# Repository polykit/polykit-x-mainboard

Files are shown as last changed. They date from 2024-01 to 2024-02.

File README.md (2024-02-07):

# Polykit X8 Mainboard

_THIS IS NOT A FINISHED PRODUCT IN ANY WAY AND STILL UNDER HEAVY DEVELOPMENT - USE AT YOUR OWN RISK!_

This repository contains Kicad schematics and PCB layout for a main board for a polyphonic synthesizer that is controlled by a micro controller.

Key features:

* 8 voice cards
* 16-bit DAC
* Atmel2560 micro controller
* Eurorack powered
* MIDI input/output

All parameters of the voice cards are controlled by the DAC. That means patches can be stored and recalled.

There is a video playlist on the design process https://makertube.net/w/p/3N2fRjXwT2SfAUv2VkMy3e

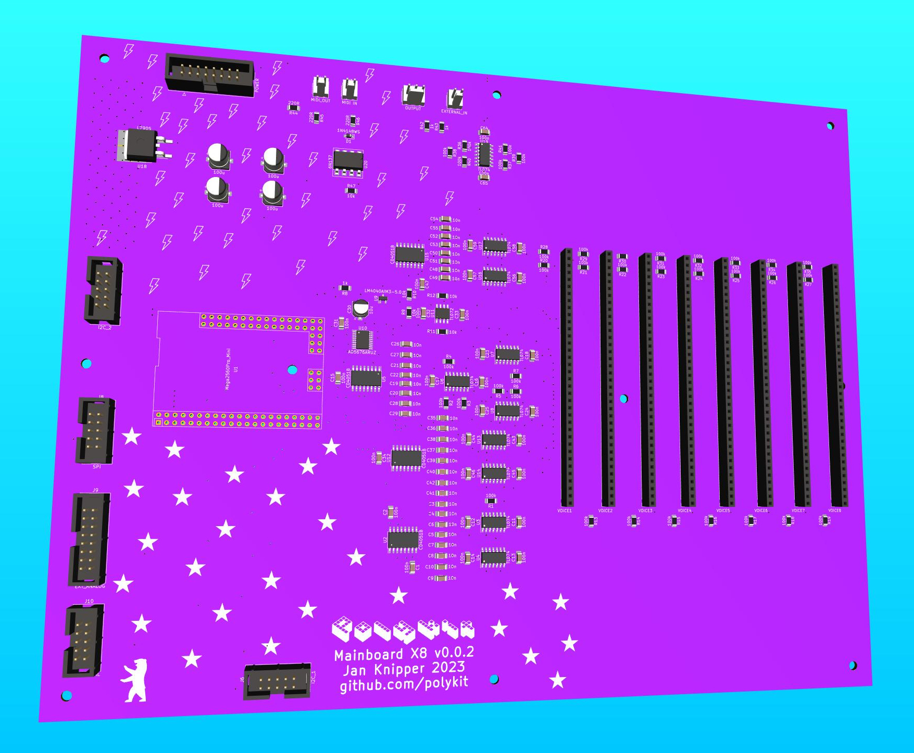
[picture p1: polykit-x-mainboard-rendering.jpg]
Polykit X8 Main Board Rendering


Related repositories:

* Voice Card: https://github.com/polykit/polykit-x-voice-card
* Control Board: https://github.com/polykit/polykit-x-controlboard
* Input Board: _soon_
* Software: _soon_
* Power Supply: https://github.com/polykit/eurorack-psu

## BOM

|Reference |Value |Footprint |Qty|
|---|---|---|---|
|C1, C2, C11-C18, C23-C25, C31-C34, C43-C47, C56-C59, C64, C65|100n ceramic |Capacitor_SMD:C_1206_3216Metric_Pad1.33x1.80mm_HandSolder |28 |
|C3-C10, C19-C22, C26-C29, C35-C42, C48-C55 |10n film, PPS |Capacitor_SMD:C_1206_3216Metric_Pad1.33x1.80mm_HandSolder |32 |
|C30 |10u |Capacitor_SMD:CP_Elec_5x5.9 |1  |
|C60-C63 |100u |Capacitor_SMD:CP_Elec_6.3x7.7 |4  |
|D1 |1N4148WS |Diode_SMD:D_SOD-323_HandSoldering |1  |
|J1 |POWER |Connector_IDC:IDC-Header_2x08_P2.54mm_Vertical |1  |
|J2 |OUTPUT |Connector_Molex:Molex_KK-254_AE-6410-03A_1x03_P2.54mm_Vertical|1  |
|J3 |MIDI IN |Connector_Molex:Molex_KK-254_AE-6410-02A_1x02_P2.54mm_Vertical|1  |
|J4 |MIDI_OUT |Connector_Molex:Molex_KK-254_AE-6410-02A_1x02_P2.54mm_Vertical|1  |
|J5 |EXTERNAL_IN |Connector_Molex:Molex_KK-254_AE-6410-02A_1x02_P2.54mm_Vertical|1  |
|J6 |I2C_1 |Connector_IDC:IDC-Header_2x05_P2.54mm_Vertical |1  |
|J7 |I2C_2 |Connector_IDC:IDC-Header_2x05_P2.54mm_Vertical |1  |
|J8 |SPI |Connector_IDC:IDC-Header_2x05_P2.54mm_Vertical |1  |
|J9 |EXT_ANALOG |Connector_IDC:IDC-Header_2x08_P2.54mm_Vertical |1  |
|J10 |EXT_DIGITAL |Connector_IDC:IDC-Header_2x05_P2.54mm_Vertical |1  |
|R1-R7, R13-R41 |100k |Resistor_SMD:R_1206_3216Metric_Pad1.30x1.75mm_HandSolder |36 |
|R8, R42, R43 |1k |Resistor_SMD:R_1206_3216Metric_Pad1.30x1.75mm_HandSolder |3  |
|R9-R12, R47 |10k |Resistor_SMD:R_1206_3216Metric_Pad1.30x1.75mm_HandSolder |5  |
|R44-R46 |220R |Resistor_SMD:R_1206_3216Metric_Pad1.30x1.75mm_HandSolder |3  |
|U1 |Mega2560Pro_Mini|aga:Mega2560Pro_Embed_RobotDyn |1  |
|U2, U5, U12, U15 |CD4051B |Package_SO:SO-16_5.3x10.2mm_P1.27mm |4  |
|U3, U4, U6-U8, U13, U14, U16, U17, U19 |TL074 |Package_SO:SO-14_3.9x8.65mm_P1.27mm |10 |
|U9 |LM4040AIM3-5.0  |Package_TO_SOT_SMD:SOT-23 |1  |
|U10 |AD5676ARUZ |Package_SO:TSSOP-20_4.4x6.5mm_P0.65mm |1  |
|U11 |TL072 |Package_SO:SO-8_3.9x4.9mm_P1.27mm |1  |
|U18 |L7905 |Package_TO_SOT_SMD:TO-263-2 |1  |
|U20 |6N137 |Package_DIP:DIP-8_W7.62mm_SMDSocket_SmallPads |1  |
|VOICE1-VOICE8 |VOICE |Connector_PinSocket_2.54mm:PinSocket_1x36_P2.54mm_Vertical |8  |

## Tweaks

* If saw/triangle signal is not audible replace R38 with a 220k resistor on the voice cards

## References

https://www.analog.com/media/en/technical-documentation/data-sheets/ad5676.pdf

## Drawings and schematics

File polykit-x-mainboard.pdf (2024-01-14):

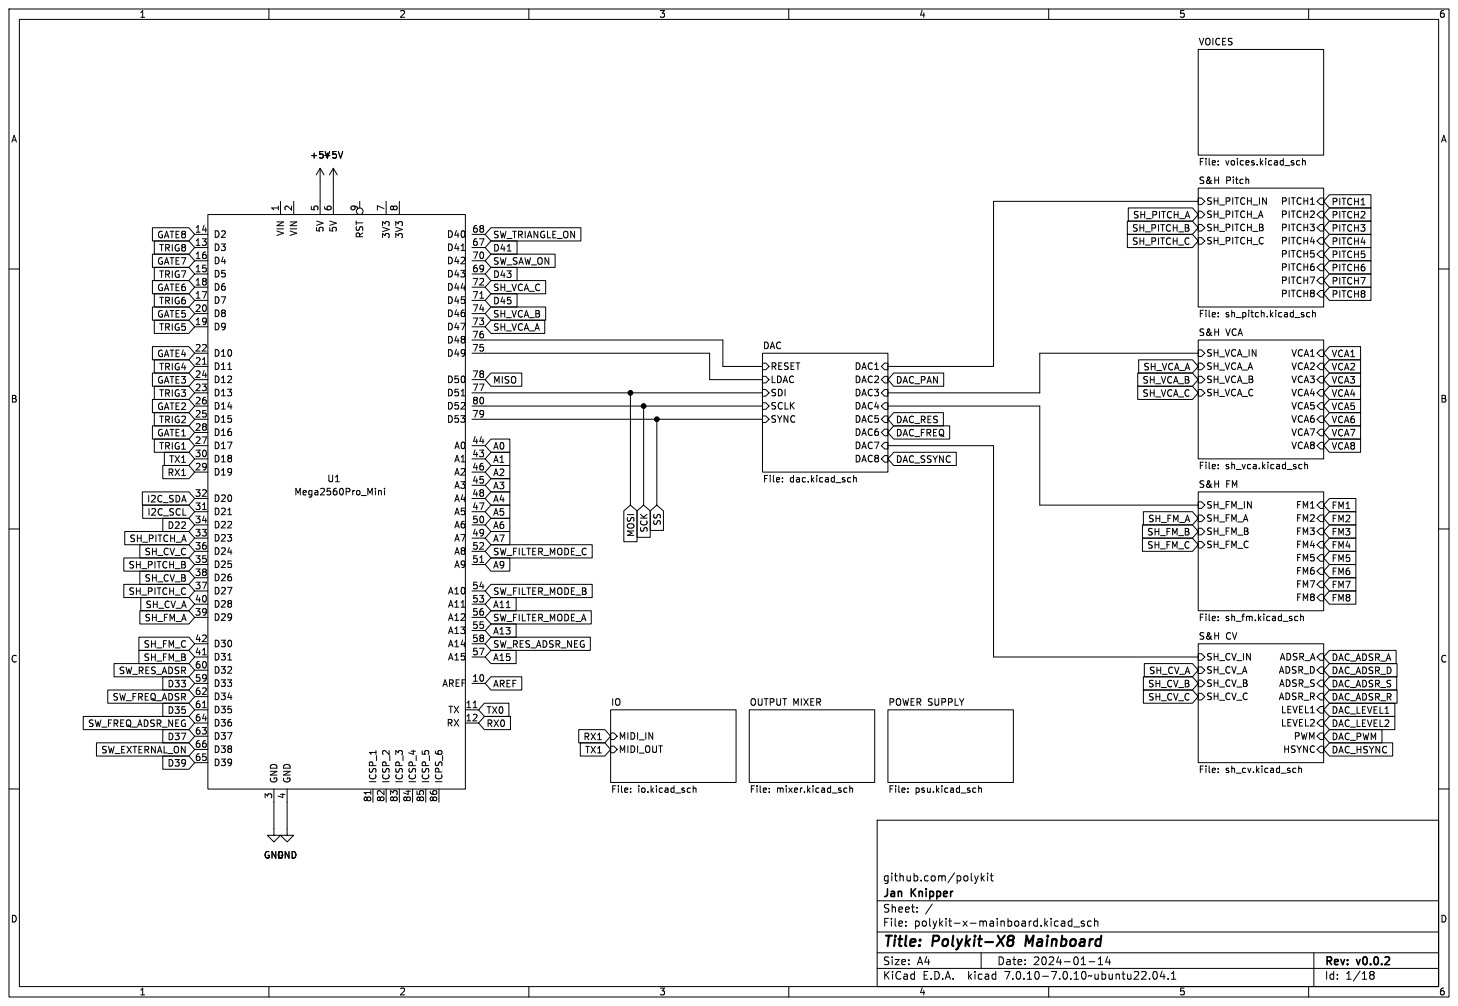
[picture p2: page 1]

SH_VCA_B
File: dac.kicad_sch OUTPUT MIXER

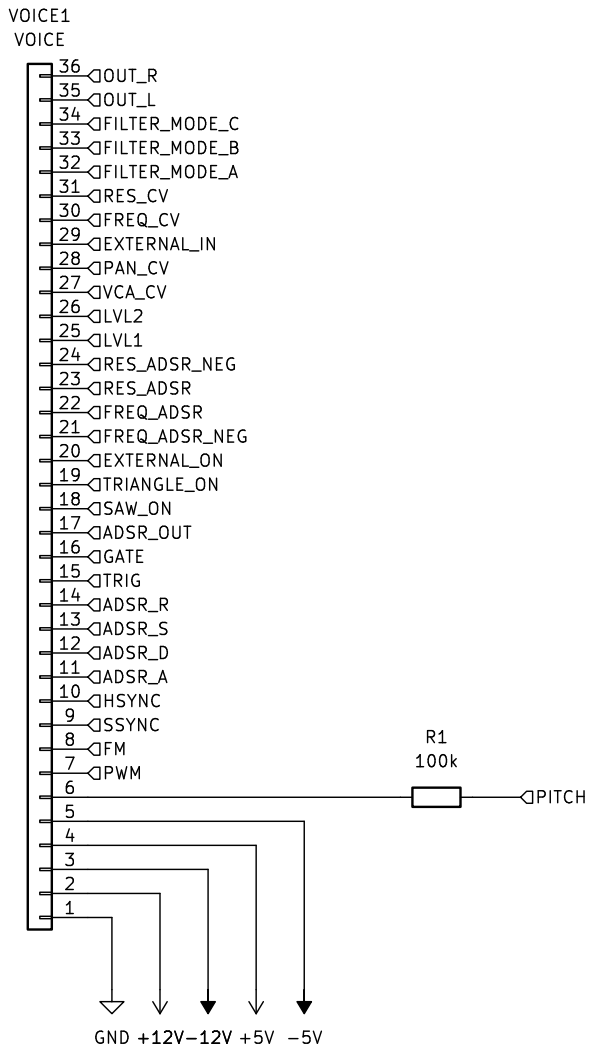
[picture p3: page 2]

github.com/polykit GND +12V -12V +5V -5V 1

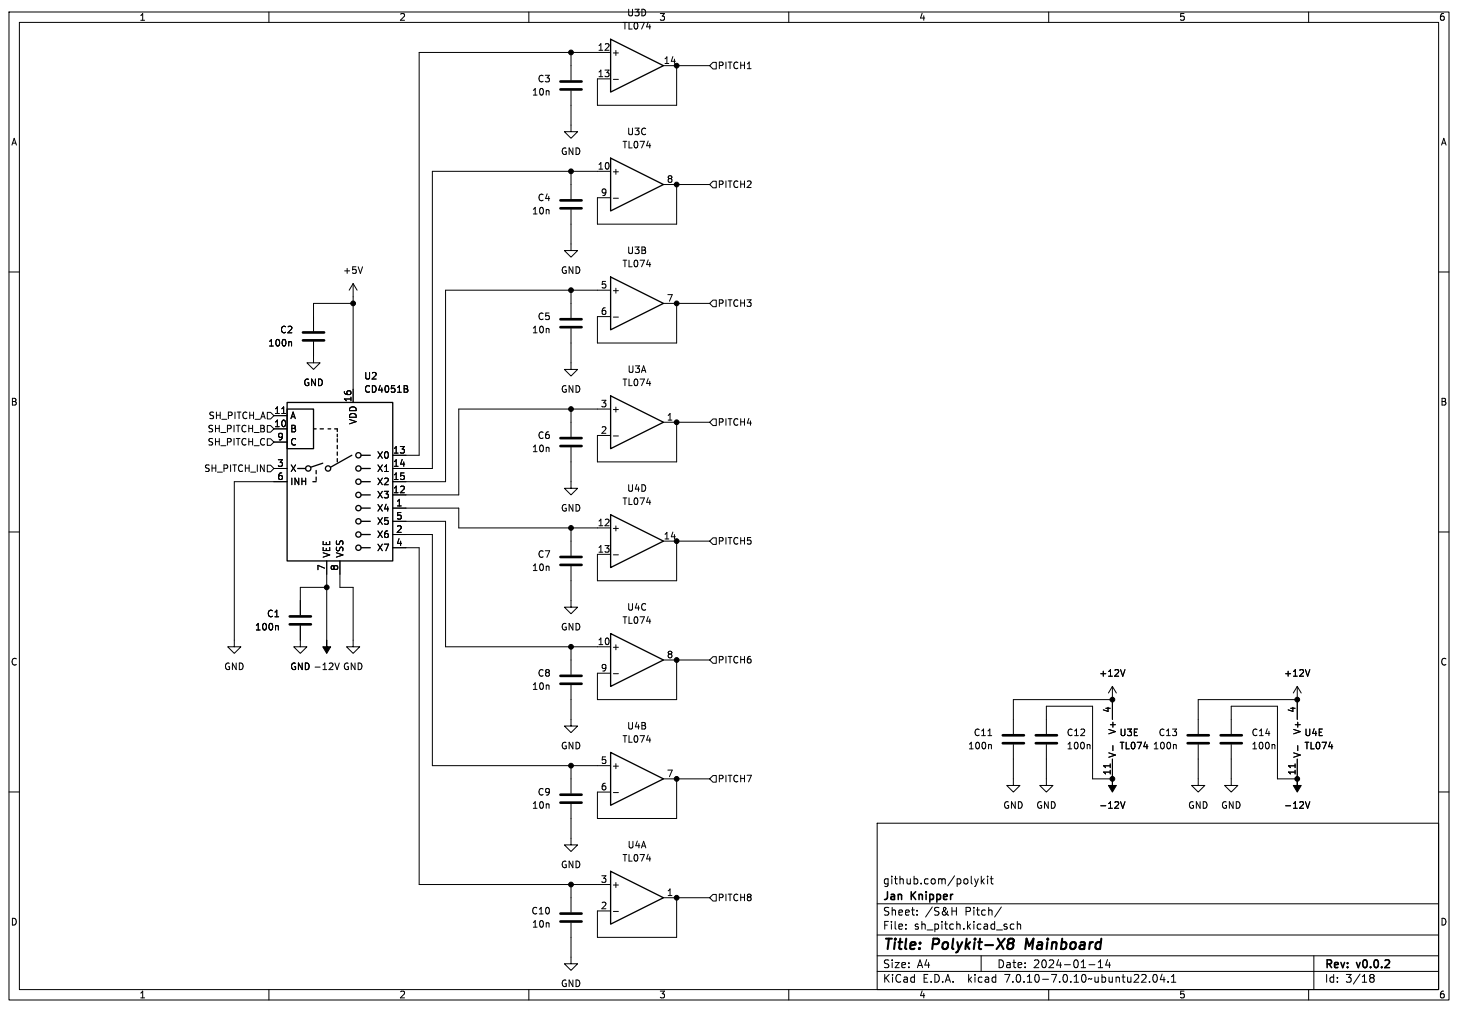
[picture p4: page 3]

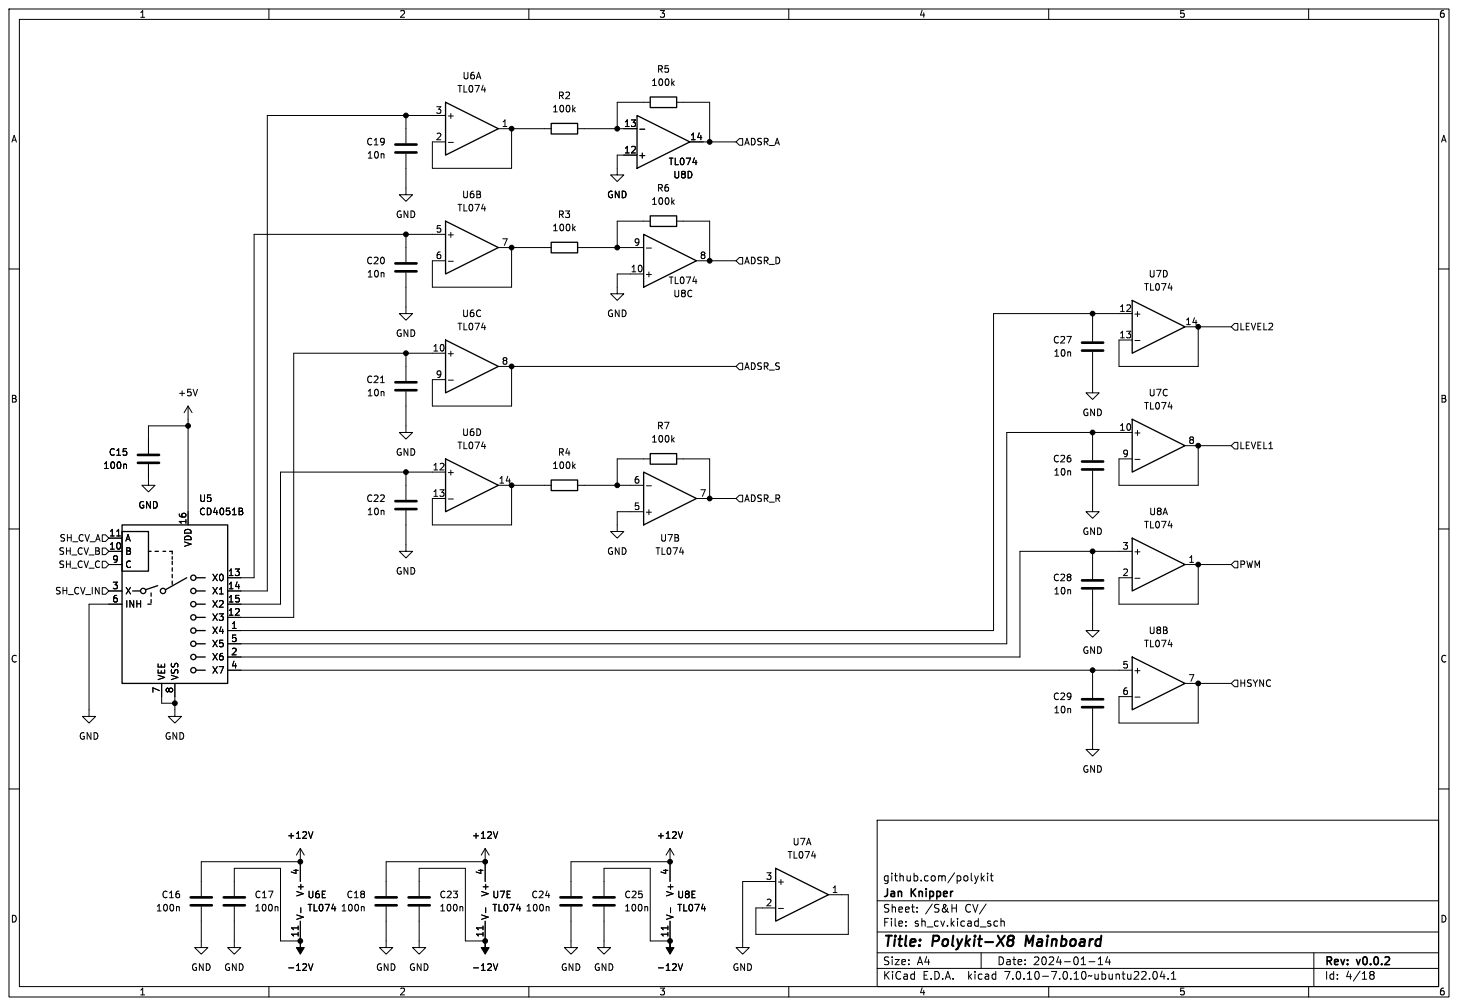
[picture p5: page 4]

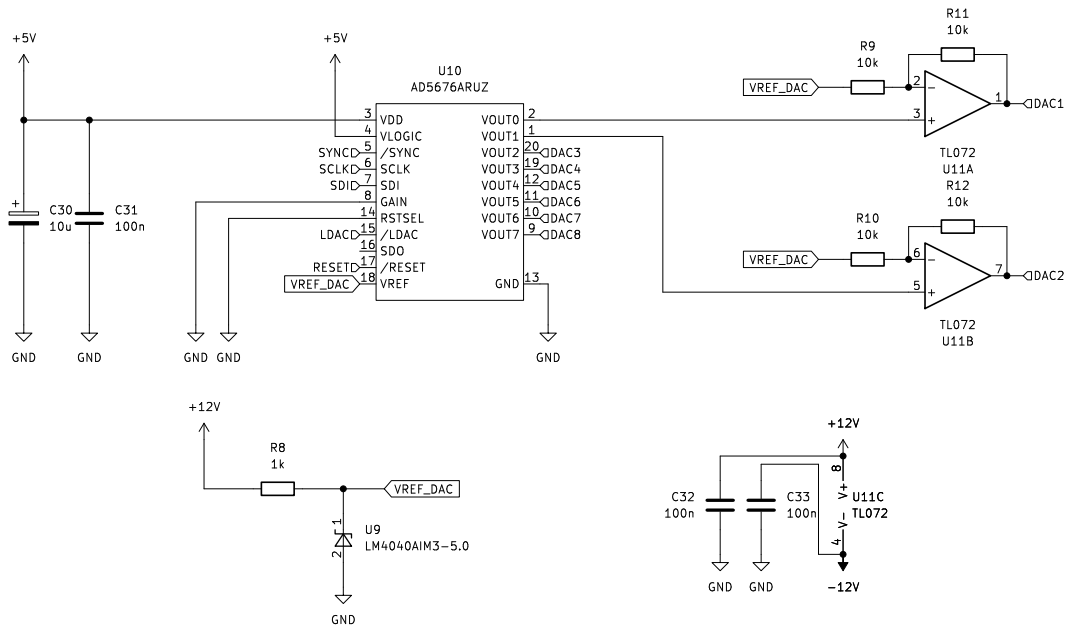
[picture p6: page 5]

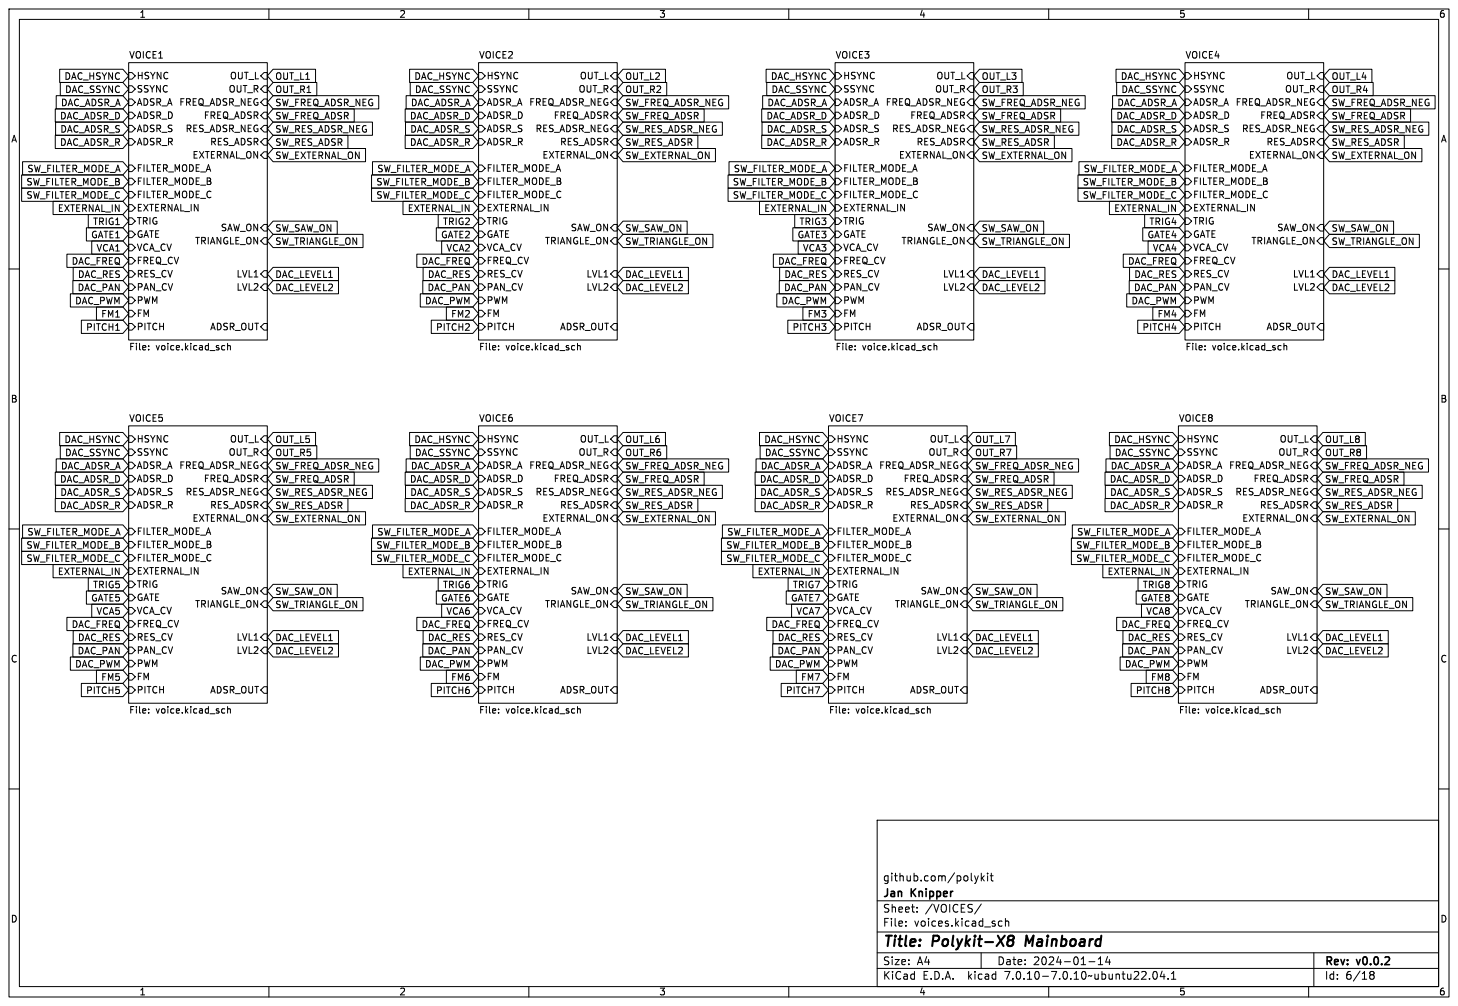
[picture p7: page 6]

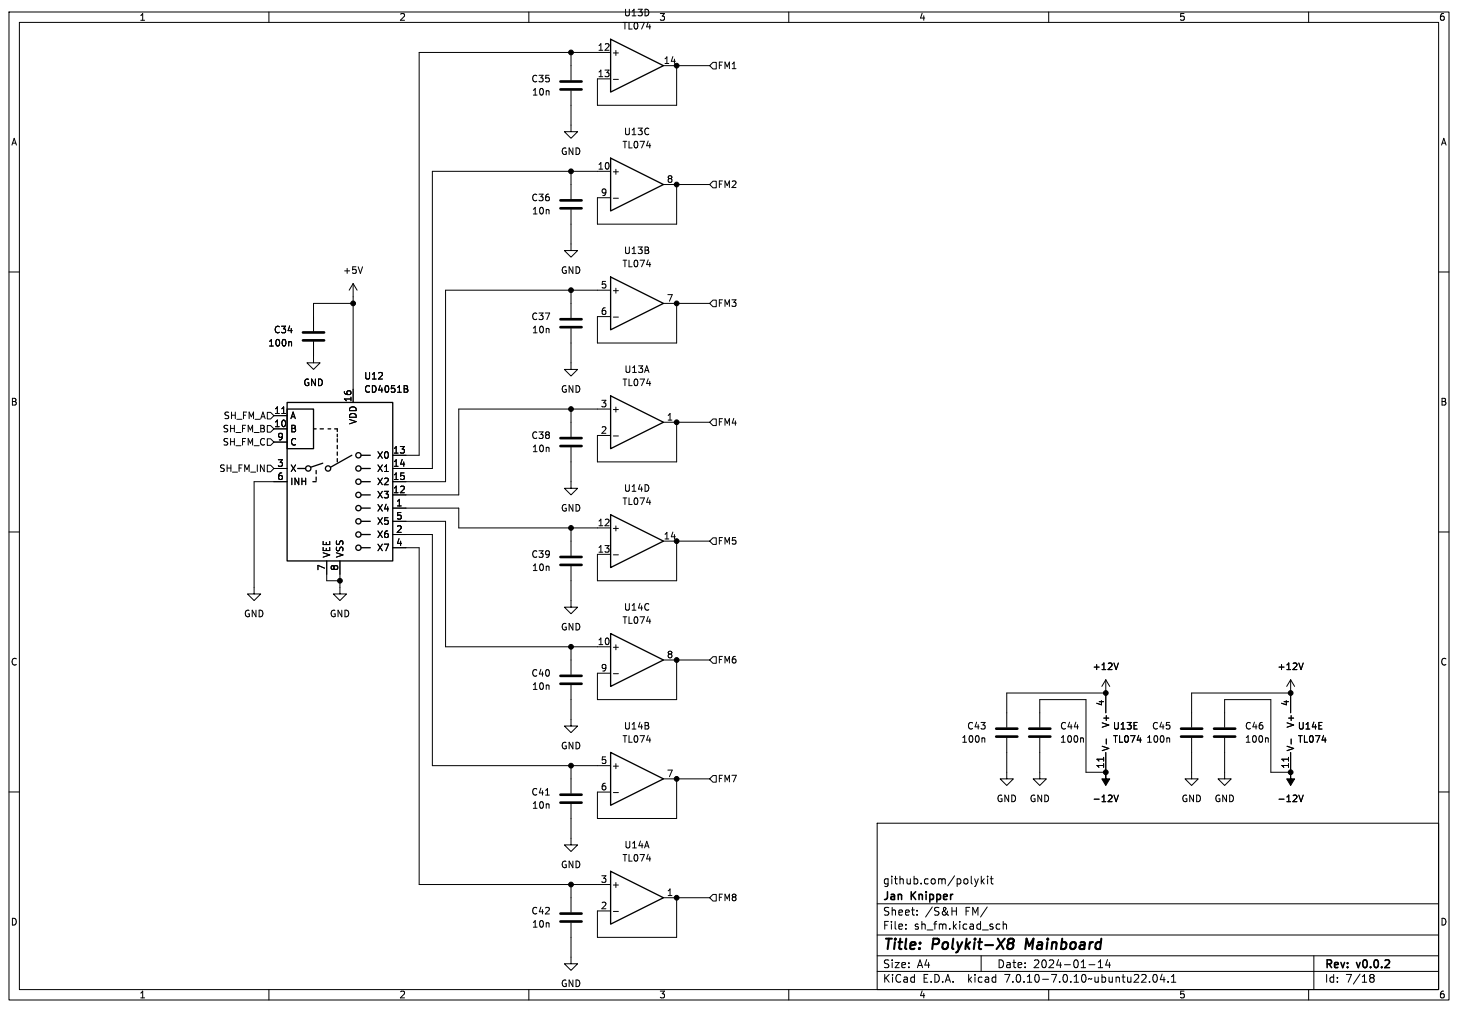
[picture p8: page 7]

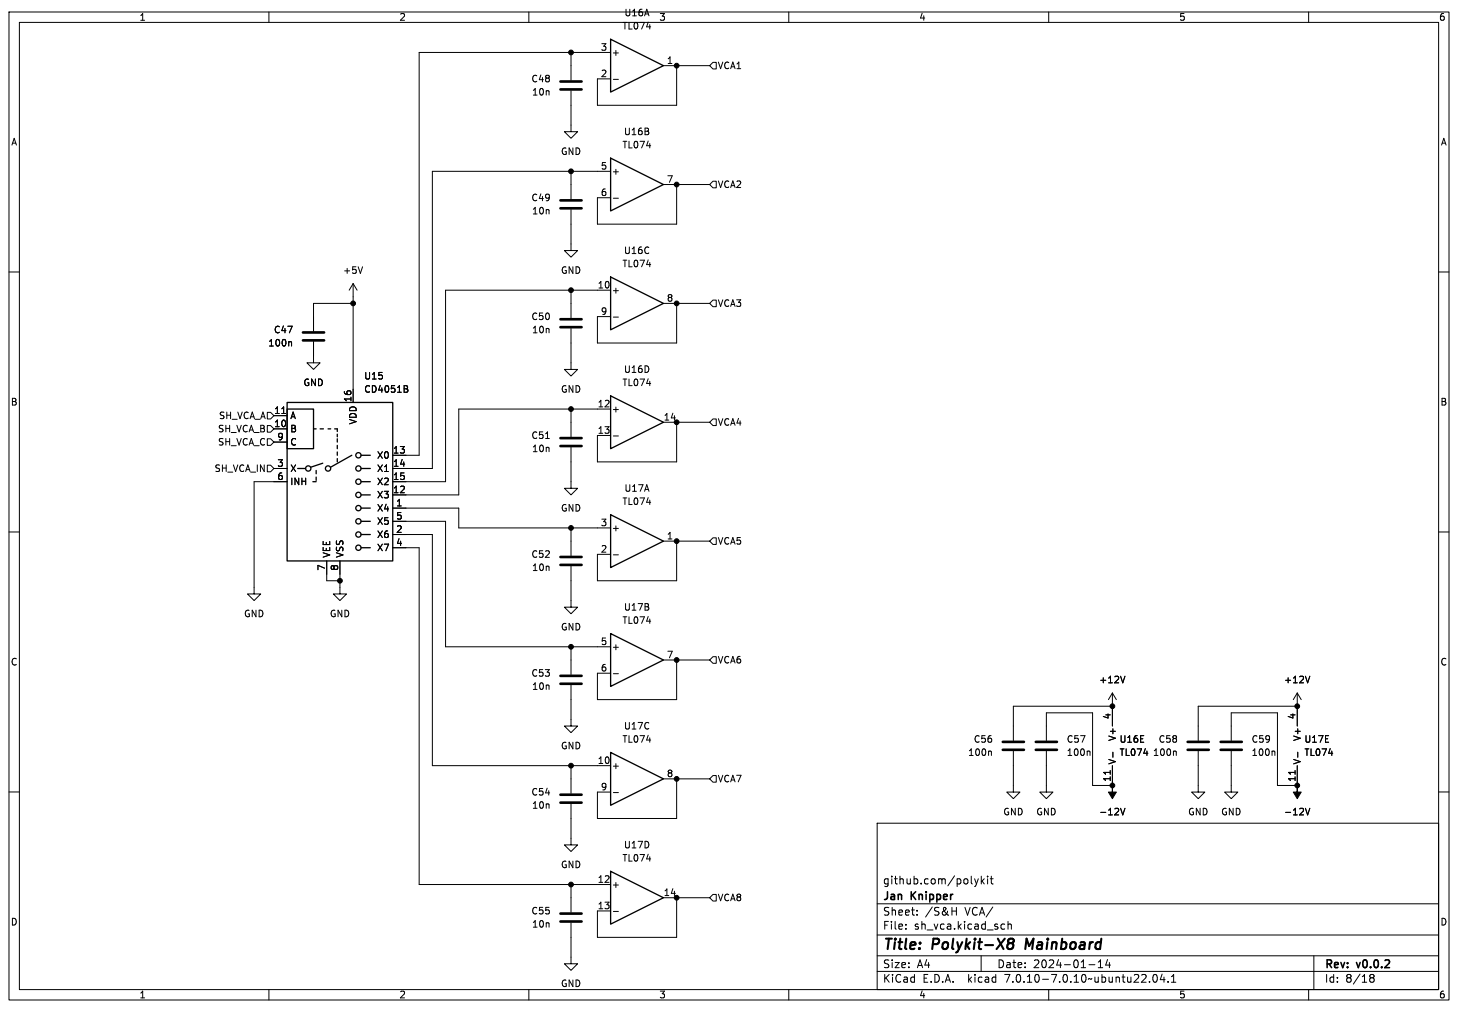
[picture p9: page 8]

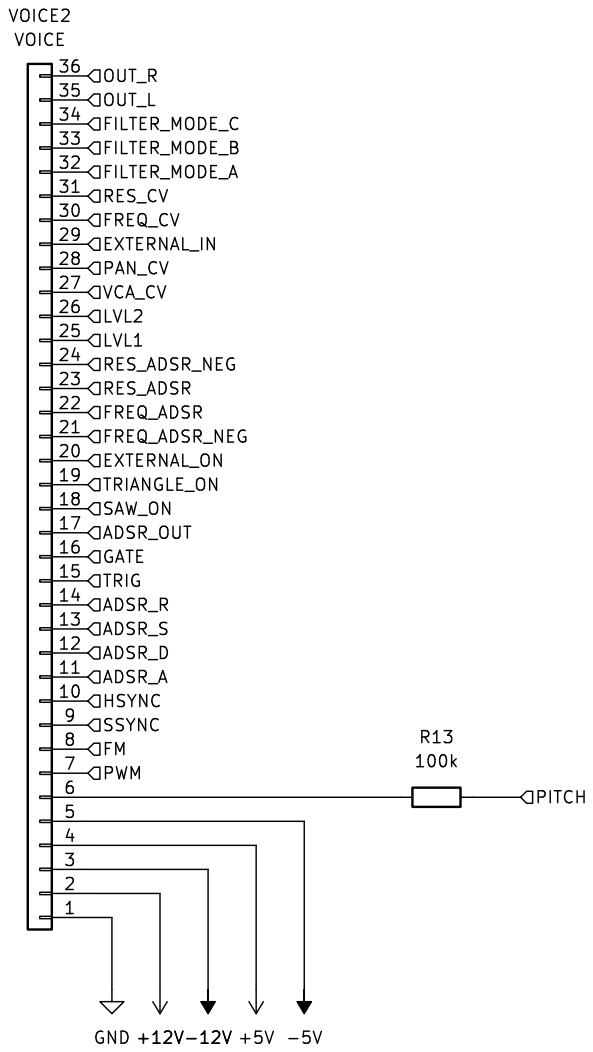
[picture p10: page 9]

github.com/polykit GND +12V -12V +5V -5V 1

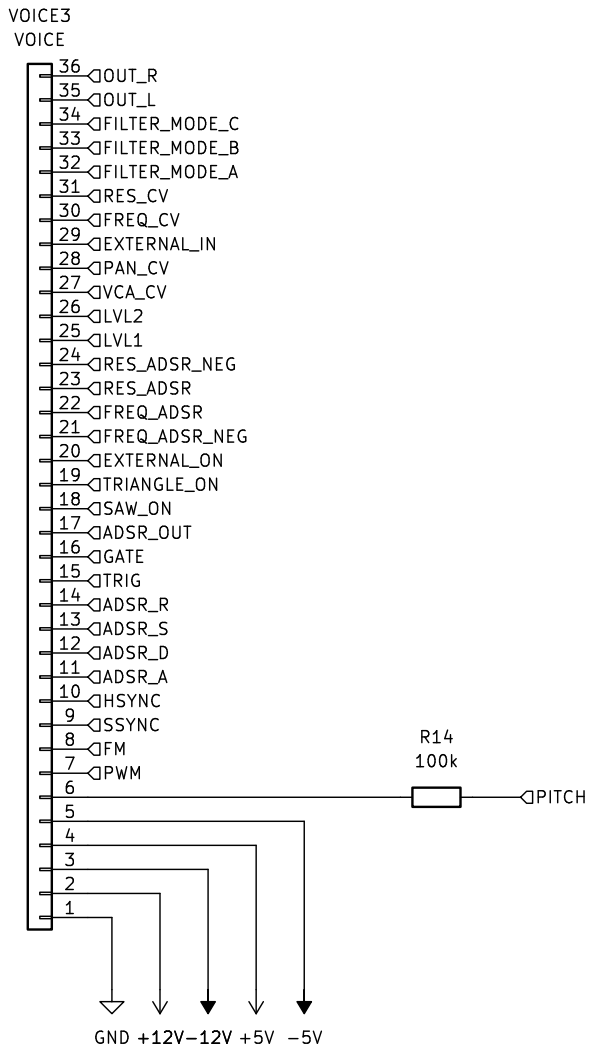
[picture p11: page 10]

github.com/polykit GND +12V -12V +5V -5V 1

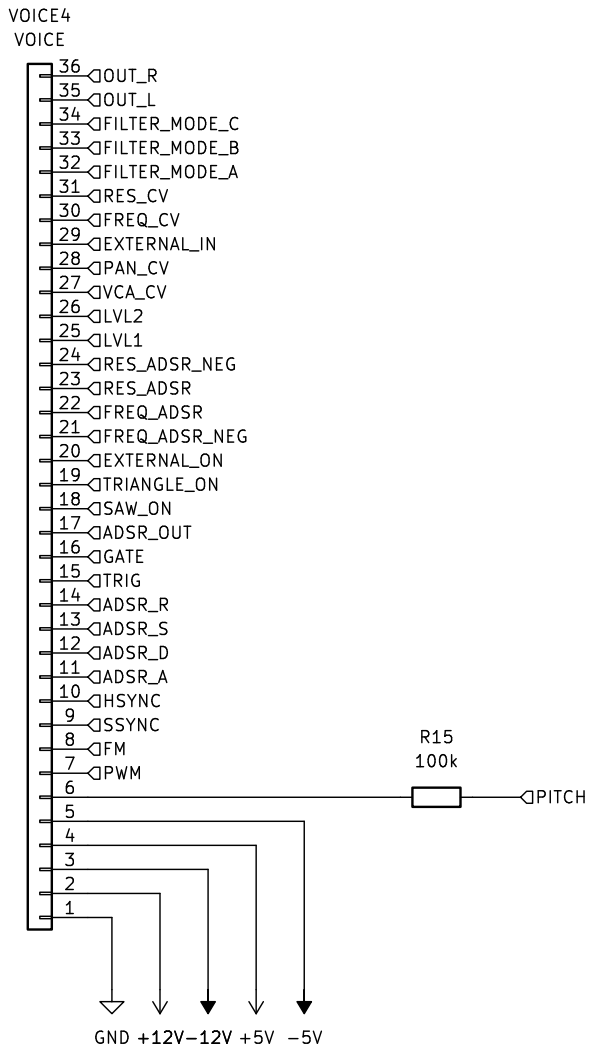
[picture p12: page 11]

github.com/polykit GND +12V -12V +5V -5V 1

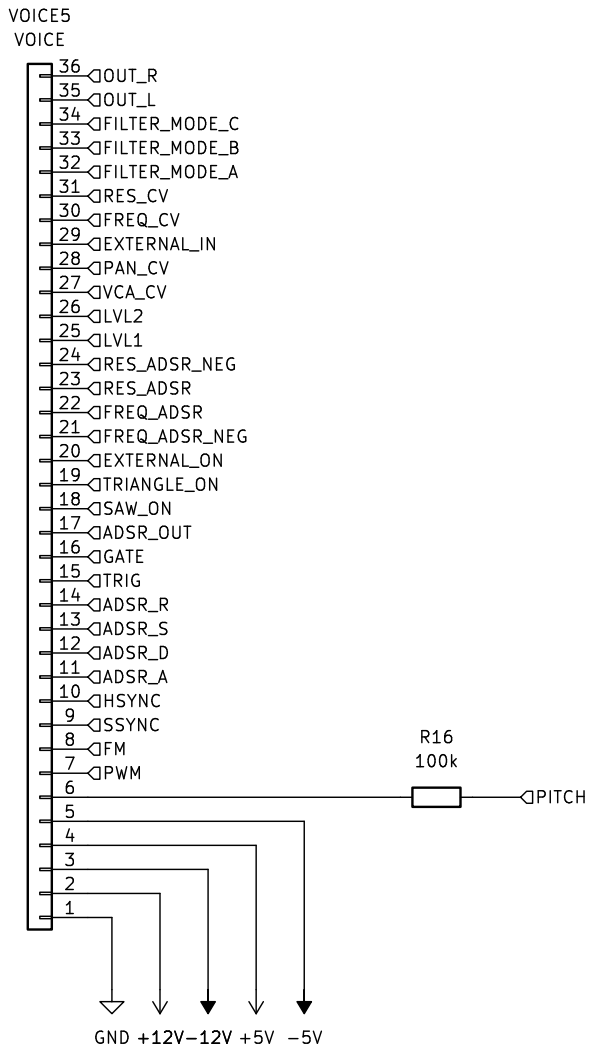
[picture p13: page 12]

github.com/polykit GND +12V -12V +5V -5V 1


github.com/polykit GND +12V -12V +5V -5V 1


github.com/polykit GND +12V -12V +5V -5V 1


github.com/polykit GND +12V -12V +5V -5V 1




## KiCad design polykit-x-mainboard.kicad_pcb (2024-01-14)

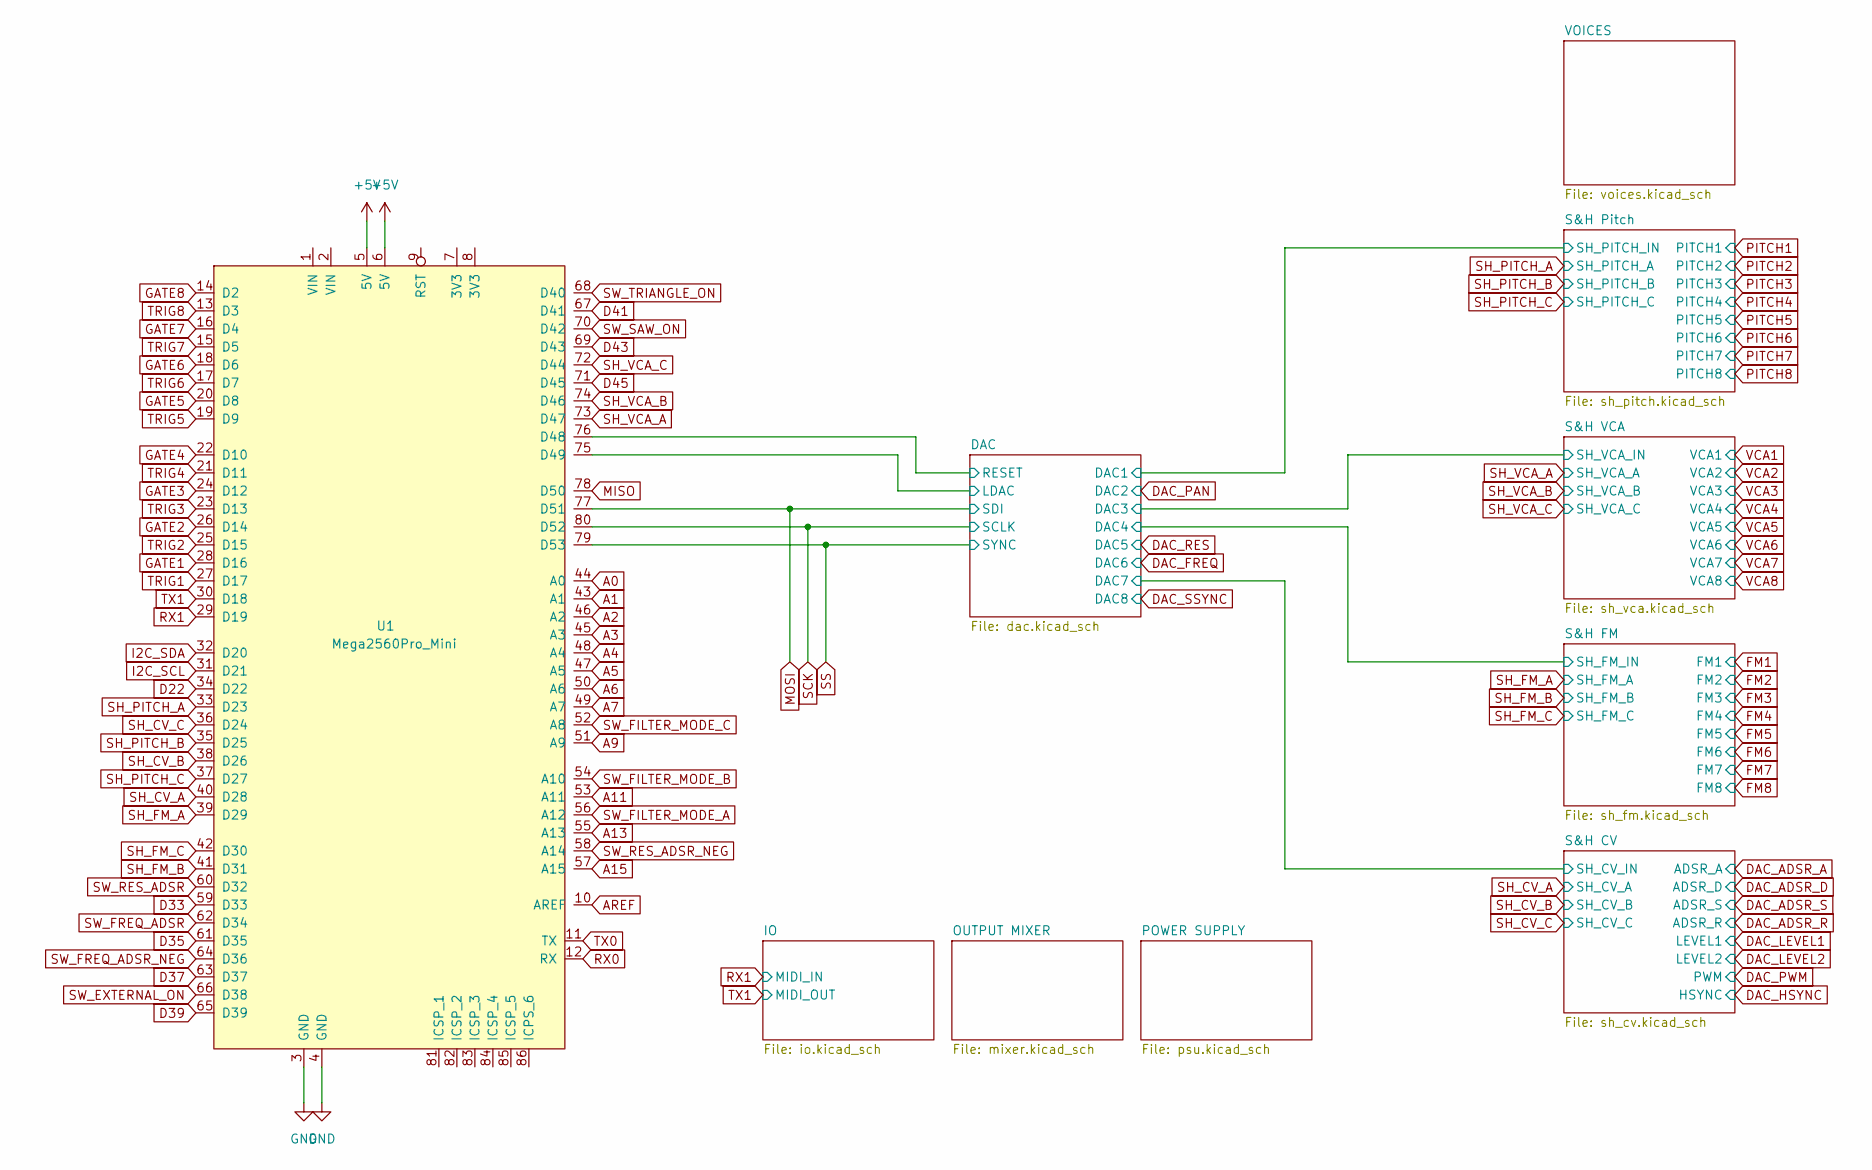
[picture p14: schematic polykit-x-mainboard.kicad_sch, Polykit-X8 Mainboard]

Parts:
U1: Mega2560Pro_Mini; Mega2560Pro_Embed_RobotDyn

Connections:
+5V: U1.5 (5V), U1.6 (5V); also elsewhere on the board
/DAC/LDAC: U1.75 (D49); also elsewhere on the board
/DAC/RESET: U1.76 (D48); also elsewhere on the board
A0: U1.44 (A0); also elsewhere on the board
A1: U1.43 (A1); also elsewhere on the board
A2: U1.46 (A2); also elsewhere on the board
A3: U1.45 (A3); also elsewhere on the board
A4: U1.48 (A4); also elsewhere on the board
A5: U1.47 (A5); also elsewhere on the board
A6: U1.50 (A6); also elsewhere on the board
A7: U1.49 (A7); also elsewhere on the board
A9: U1.51 (A9); also elsewhere on the board
A11: U1.53 (A11); also elsewhere on the board
A13: U1.55 (A13); also elsewhere on the board
A15: U1.57 (A15); also elsewhere on the board
AREF: U1.10 (AREF); also elsewhere on the board
D22: U1.34 (D22); also elsewhere on the board
D33: U1.59 (D33); also elsewhere on the board
D35: U1.61 (D35); also elsewhere on the board
D37: U1.63 (D37); also elsewhere on the board
D39: U1.65 (D39); also elsewhere on the board
D41: U1.67 (D41); also elsewhere on the board
D43: U1.69 (D43); also elsewhere on the board
D45: U1.71 (D45); also elsewhere on the board
GATE1: U1.28 (D16); also elsewhere on the board
GATE2: U1.26 (D14); also elsewhere on the board
GATE3: U1.24 (D12); also elsewhere on the board
GATE4: U1.22 (D10); also elsewhere on the board
GATE5: U1.20 (D8); also elsewhere on the board
GATE6: U1.18 (D6); also elsewhere on the board
GATE7: U1.16 (D4); also elsewhere on the board
GATE8: U1.14 (D2); also elsewhere on the board
GND: U1.3 (GND), U1.4 (GND); also elsewhere on the board
I2C_SCL: U1.31 (D21); also elsewhere on the board
I2C_SDA: U1.32 (D20); also elsewhere on the board
MISO: U1.78 (D50); also elsewhere on the board
MOSI: U1.77 (D51); also elsewhere on the board
RX0: U1.12 (RX); also elsewhere on the board
RX1: U1.29 (D19); also elsewhere on the board
SCK: U1.80 (D52); also elsewhere on the board
SH_CV_A: U1.40 (D28); also elsewhere on the board
SH_CV_B: U1.38 (D26); also elsewhere on the board
SH_CV_C: U1.36 (D24); also elsewhere on the board
SH_FM_A: U1.39 (D29); also elsewhere on the board
SH_FM_B: U1.41 (D31); also elsewhere on the board
SH_FM_C: U1.42 (D30); also elsewhere on the board
SH_PITCH_A: U1.33 (D23); also elsewhere on the board
SH_PITCH_B: U1.35 (D25); also elsewhere on the board
SH_PITCH_C: U1.37 (D27); also elsewhere on the board
SH_VCA_A: U1.73 (D47); also elsewhere on the board
SH_VCA_B: U1.74 (D46); also elsewhere on the board
SH_VCA_C: U1.72 (D44); also elsewhere on the board
SS: U1.79 (D53); also elsewhere on the board
SW_EXTERNAL_ON: U1.66 (D38); also elsewhere on the board
SW_FILTER_MODE_A: U1.56 (A12); also elsewhere on the board
SW_FILTER_MODE_B: U1.54 (A10); also elsewhere on the board
SW_FILTER_MODE_C: U1.52 (A8); also elsewhere on the board
SW_FREQ_ADSR: U1.62 (D34); also elsewhere on the board
SW_FREQ_ADSR_NEG: U1.64 (D36); also elsewhere on the board
SW_RES_ADSR: U1.60 (D32); also elsewhere on the board
SW_RES_ADSR_NEG: U1.58 (A14); also elsewhere on the board
SW_SAW_ON: U1.70 (D42); also elsewhere on the board
SW_TRIANGLE_ON: U1.68 (D40); also elsewhere on the board
TRIG1: U1.27 (D17); also elsewhere on the board
TRIG2: U1.25 (D15); also elsewhere on the board
TRIG3: U1.23 (D13); also elsewhere on the board
TRIG4: U1.21 (D11); also elsewhere on the board
TRIG5: U1.19 (D9); also elsewhere on the board
TRIG6: U1.17 (D7); also elsewhere on the board
TRIG7: U1.15 (D5); also elsewhere on the board
TRIG8: U1.13 (D3); also elsewhere on the board
TX0: U1.11 (TX); also elsewhere on the board
TX1: U1.30 (D18); also elsewhere on the board

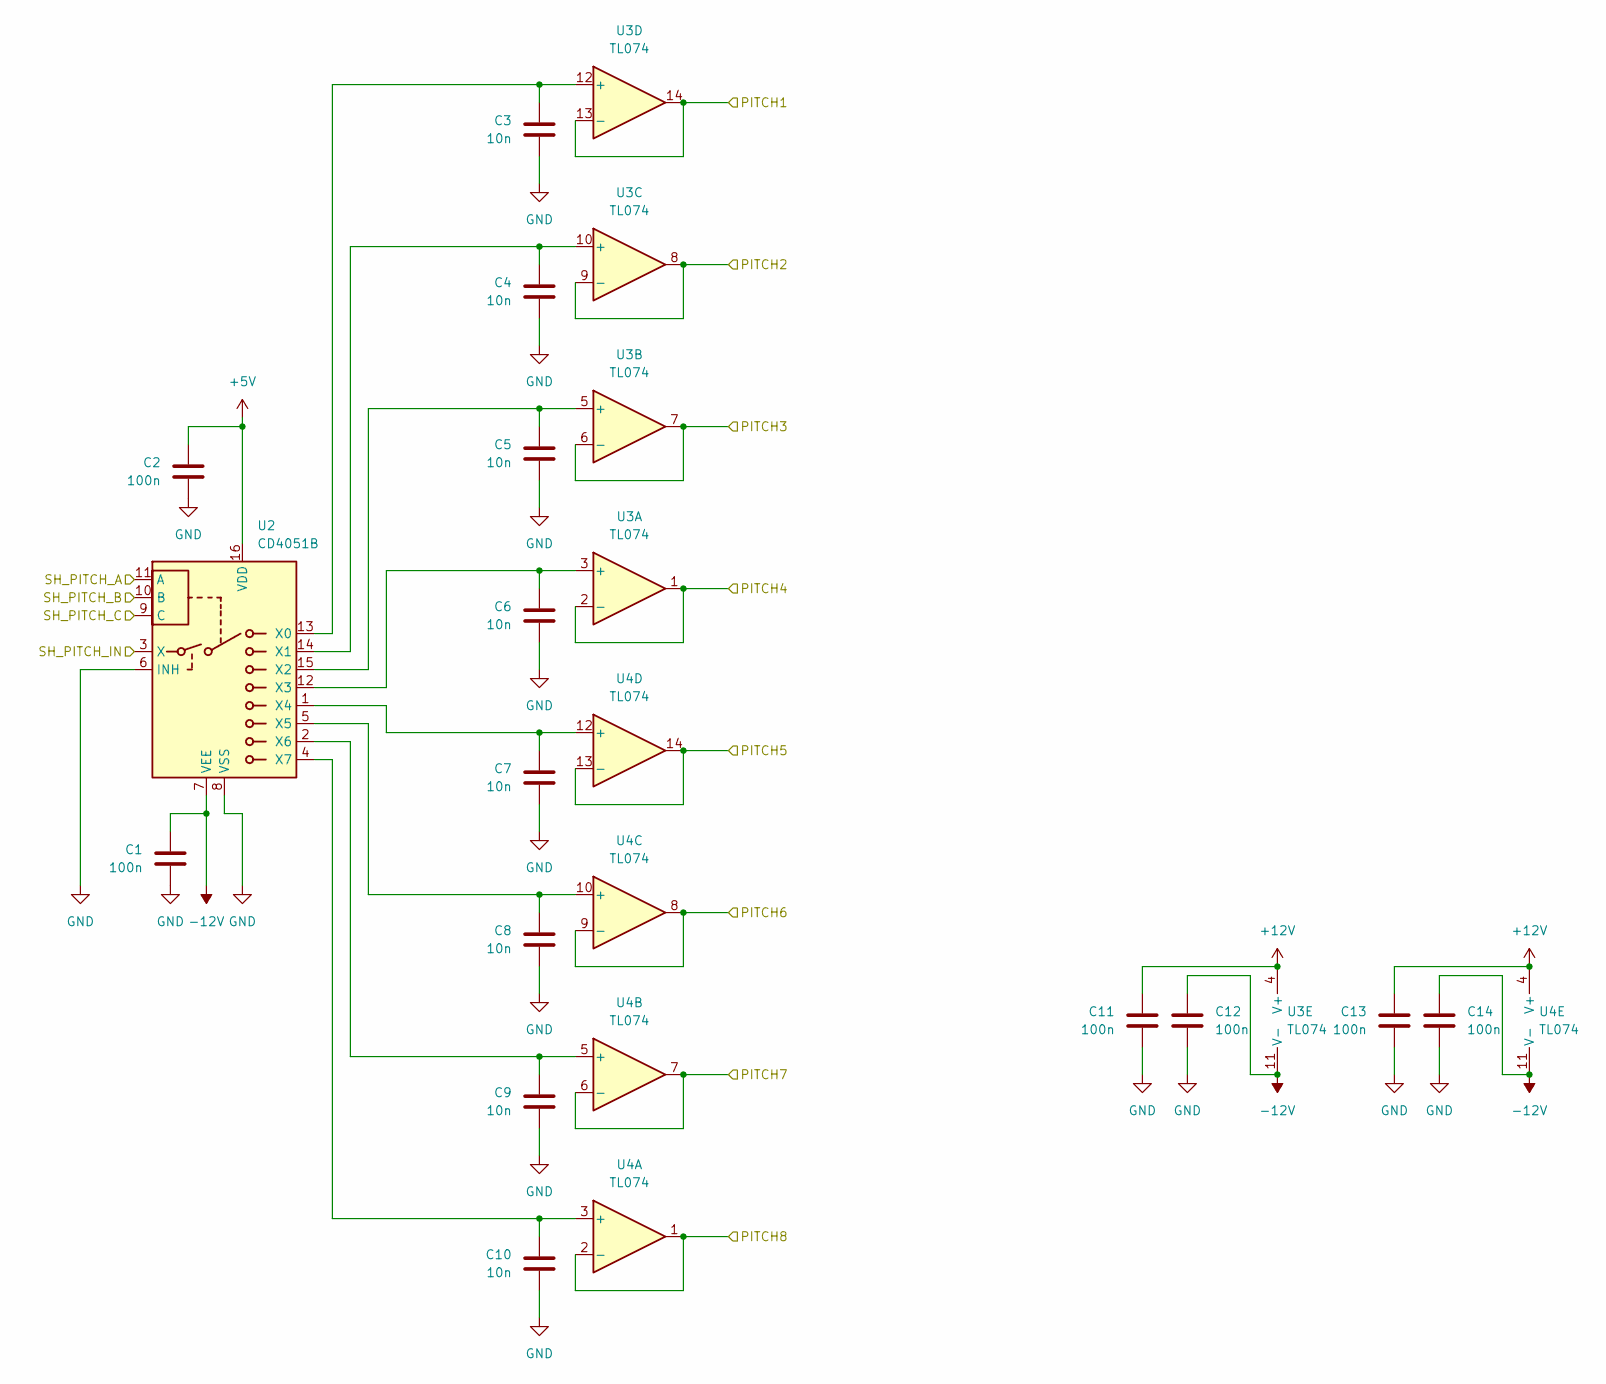
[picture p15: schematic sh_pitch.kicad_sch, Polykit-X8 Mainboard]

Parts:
C1, C2, C11, C12, C13, C14: 100n; C_1206_3216Metric_Pad1.33x1.80mm_HandSolder
C3, C4, C5, C6, C7, C8, C9, C10: 10n; C_1206_3216Metric_Pad1.33x1.80mm_HandSolder
U2: CD4051B; SO-16_5.3x10.2mm_P1.27mm
U3, U4: TL074; SO-14_3.9x8.65mm_P1.27mm

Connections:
+5V: C2.1, U2.16 (VDD); also elsewhere on the board
+12V: C11.1, C13.1, U3.4 (V+), U4.4 (V+); also elsewhere on the board
-12V: C1.1, C12.1, C14.1, U2.7 (VEE), U3.11 (V-), U4.11 (V-); also elsewhere on the board
/DAC/DAC1: U2.3 (X); also elsewhere on the board
GND: C1.2, C2.2, C3.2, C4.2, C5.2, C6.2, C7.2, C8.2, C9.2, C10.2, C11.2, C12.2, C13.2, C14.2, U2.6 (INH), U2.8 (VSS); also elsewhere on the board
unnamed: C3.1, U2.13 (X0), U3.12 (+)
unnamed: C4.1, U2.14 (X1), U3.10 (+)
unnamed: C5.1, U2.15 (X2), U3.5 (+)
unnamed: C6.1, U2.12 (X3), U3.3 (+)
unnamed: C7.1, U2.1 (X4), U4.12 (+)
unnamed: C8.1, U2.5 (X5), U4.10 (+)
unnamed: C9.1, U2.2 (X6), U4.5 (+)
unnamed: C10.1, U2.4 (X7), U4.3 (+)
PITCH1: U3.13 (-), U3.14; also elsewhere on the board
PITCH2: U3.8, U3.9 (-); also elsewhere on the board
PITCH3: U3.6 (-), U3.7; also elsewhere on the board
PITCH4: U3.1, U3.2 (-); also elsewhere on the board
PITCH5: U4.13 (-), U4.14; also elsewhere on the board
PITCH6: U4.8, U4.9 (-); also elsewhere on the board
PITCH7: U4.6 (-), U4.7; also elsewhere on the board
PITCH8: U4.1, U4.2 (-); also elsewhere on the board
SH_PITCH_A: U2.11 (A); also elsewhere on the board
SH_PITCH_B: U2.10 (B); also elsewhere on the board
SH_PITCH_C: U2.9 (C); also elsewhere on the board

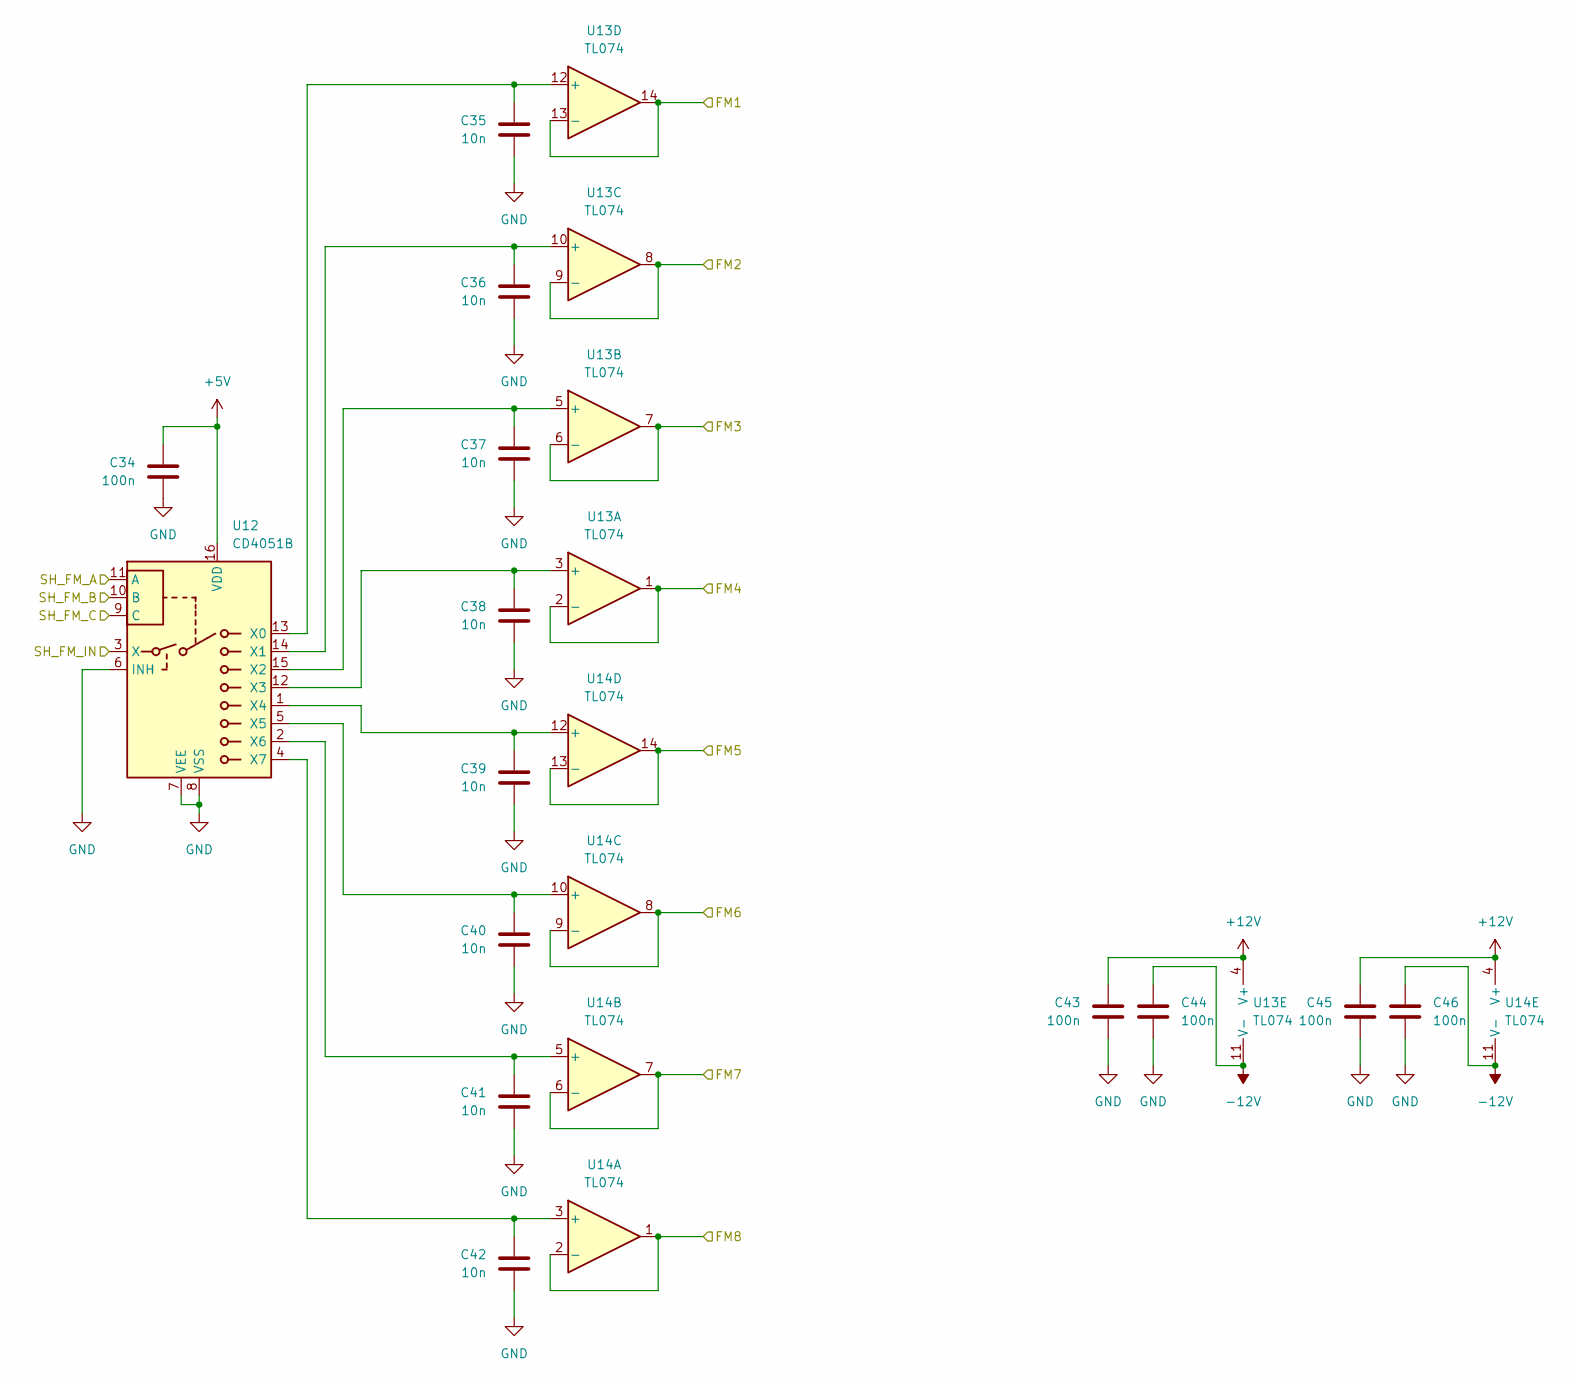
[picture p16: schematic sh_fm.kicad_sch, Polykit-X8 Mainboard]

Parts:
C34, C43, C44, C45, C46: 100n; C_1206_3216Metric_Pad1.33x1.80mm_HandSolder
C35, C36, C37, C38, C39, C40, C41, C42: 10n; C_1206_3216Metric_Pad1.33x1.80mm_HandSolder
U12: CD4051B; SO-16_5.3x10.2mm_P1.27mm
U13, U14: TL074; SO-14_3.9x8.65mm_P1.27mm

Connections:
+5V: C34.1, U12.16 (VDD); also elsewhere on the board
+12V: C43.1, C45.1, U13.4 (V+), U14.4 (V+); also elsewhere on the board
-12V: C44.1, C46.1, U13.11 (V-), U14.11 (V-); also elsewhere on the board
/DAC/DAC4: U12.3 (X); also elsewhere on the board
FM1: U13.13 (-), U13.14; also elsewhere on the board
FM2: U13.8, U13.9 (-); also elsewhere on the board
FM3: U13.6 (-), U13.7; also elsewhere on the board
FM4: U13.1, U13.2 (-); also elsewhere on the board
FM5: U14.13 (-), U14.14; also elsewhere on the board
FM6: U14.8, U14.9 (-); also elsewhere on the board
FM7: U14.6 (-), U14.7; also elsewhere on the board
FM8: U14.1, U14.2 (-); also elsewhere on the board
GND: C34.2, C35.2, C36.2, C37.2, C38.2, C39.2, C40.2, C41.2, C42.2, C43.2, C44.2, C45.2, C46.2, U12.6 (INH), U12.7 (VEE), U12.8 (VSS); also elsewhere on the board
unnamed: C35.1, U12.13 (X0), U13.12 (+)
unnamed: C36.1, U12.14 (X1), U13.10 (+)
unnamed: C37.1, U12.15 (X2), U13.5 (+)
unnamed: C38.1, U12.12 (X3), U13.3 (+)
unnamed: C39.1, U12.1 (X4), U14.12 (+)
unnamed: C40.1, U12.5 (X5), U14.10 (+)
unnamed: C41.1, U12.2 (X6), U14.5 (+)
unnamed: C42.1, U12.4 (X7), U14.3 (+)
SH_FM_A: U12.11 (A); also elsewhere on the board
SH_FM_B: U12.10 (B); also elsewhere on the board
SH_FM_C: U12.9 (C); also elsewhere on the board

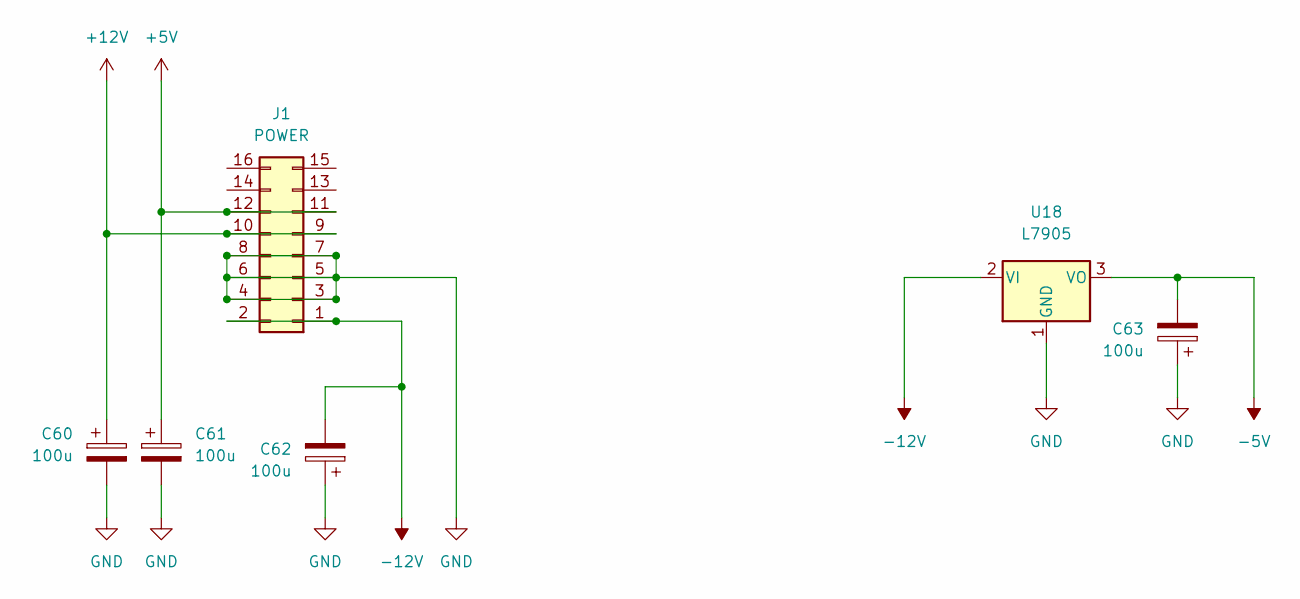
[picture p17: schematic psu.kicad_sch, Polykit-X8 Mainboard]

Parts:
C60, C61, C62, C63: 100u; CP_Elec_6.3x7.7
J1: POWER; IDC-Header_2x08_P2.54mm_Vertical
U18: L7905; TO-263-2

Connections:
+5V: C61.1, J1.11, J1.12; also elsewhere on the board
+12V: C60.1, J1.9, J1.10; also elsewhere on the board
-5V: C63.2, U18.3 (VO); also elsewhere on the board
-12V: C62.2, J1.1, J1.2, U18.2 (VI); also elsewhere on the board
GND: C60.2, C61.2, C62.1, C63.1, J1.3, J1.4, J1.5, J1.6, J1.7, J1.8, U18.1 (GND); also elsewhere on the board

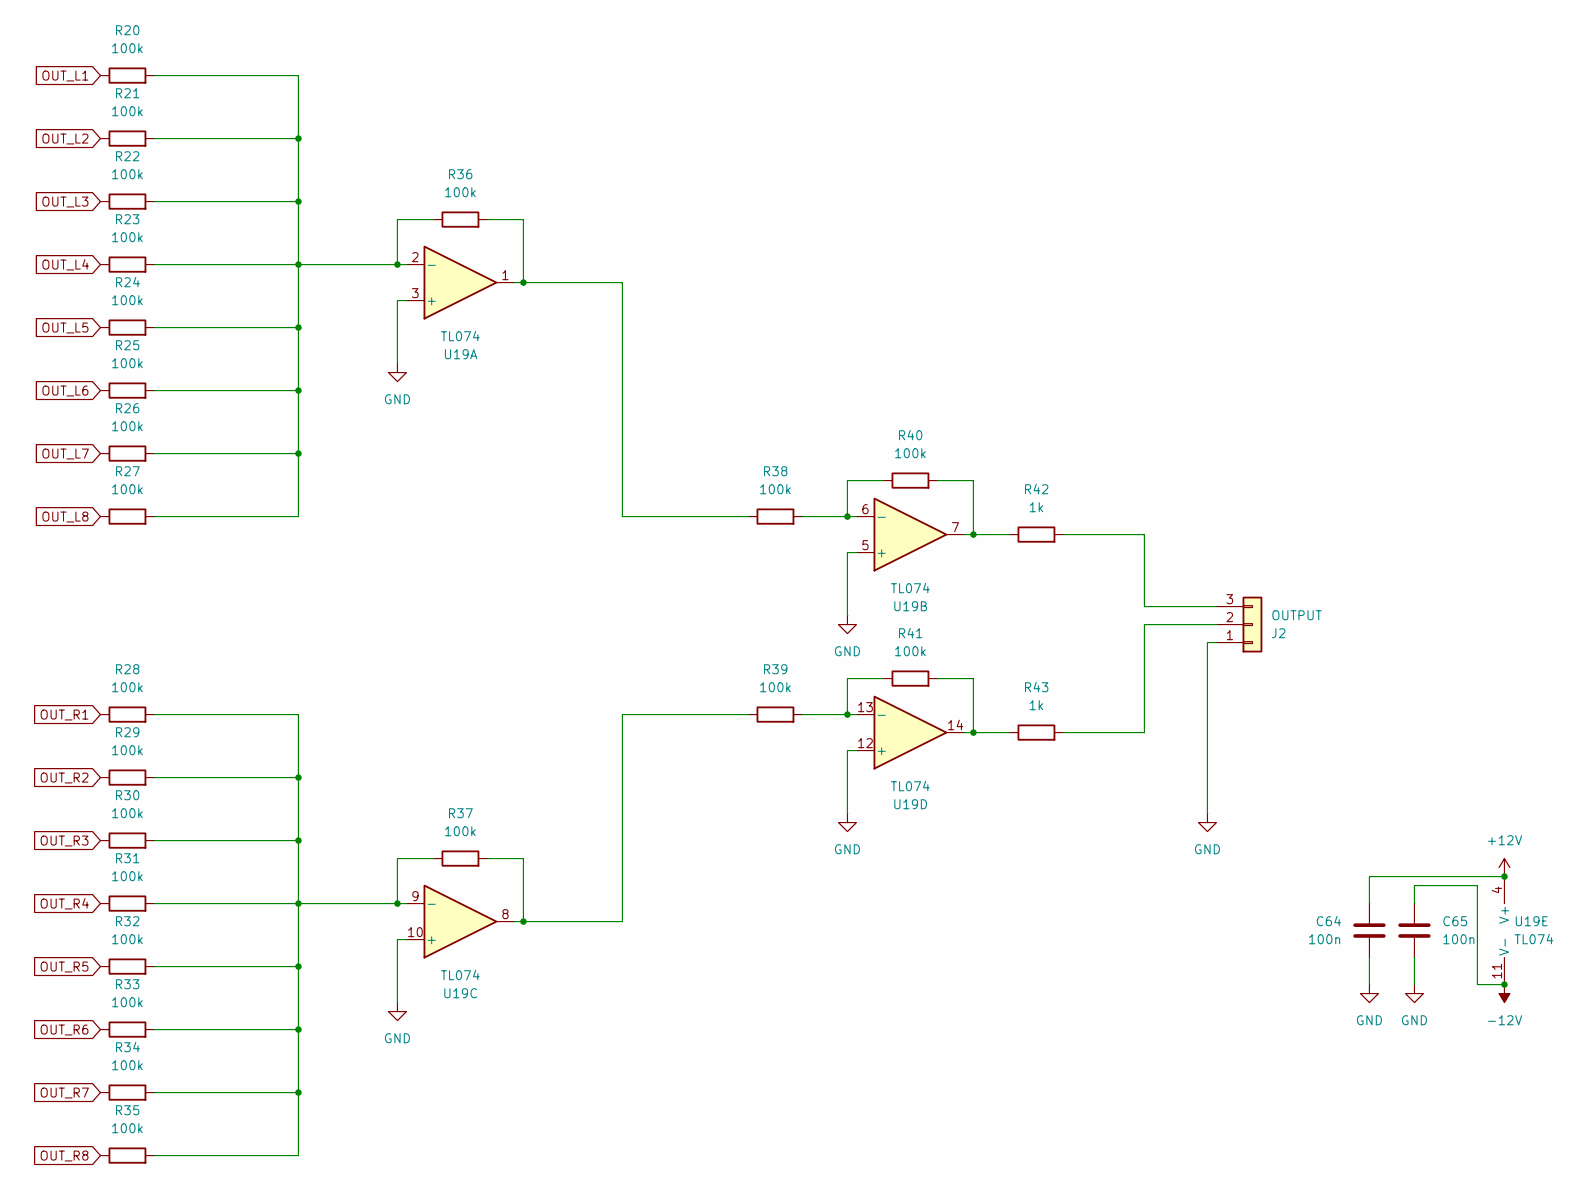
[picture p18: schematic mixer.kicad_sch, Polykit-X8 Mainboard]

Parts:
C64, C65: 100n; C_1206_3216Metric_Pad1.33x1.80mm_HandSolder
J2: OUTPUT; Molex_KK-254_AE-6410-03A_1x03_P2.54mm_Vertical
R20, R21, R22, R23, R24, R25, R26, R27, R28, R29, R30, R31, R32, R33, R34, R35, R36, R37, R38, R39, R40, R41: 100k; R_1206_3216Metric_Pad1.30x1.75mm_HandSolder
R42, R43: 1k; R_1206_3216Metric_Pad1.30x1.75mm_HandSolder
U19: TL074; SO-14_3.9x8.65mm_P1.27mm

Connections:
+12V: C64.1, U19.4 (V+); also elsewhere on the board
-12V: C65.1, U19.11 (V-); also elsewhere on the board
GND: C64.2, C65.2, J2.1, U19.3 (+), U19.5 (+), U19.10 (+), U19.12 (+); also elsewhere on the board
unnamed: J2.2, R43.2
unnamed: J2.3, R42.2
unnamed: R20.2, R21.2, R22.2, R23.2, R24.2, R25.2, R26.2, R27.2, R36.1, U19.2 (-)
unnamed: R28.2, R29.2, R30.2, R31.2, R32.2, R33.2, R34.2, R35.2, R37.1, U19.9 (-)
unnamed: R36.2, R38.1, U19.1
unnamed: R37.2, R39.1, U19.8
unnamed: R38.2, R40.1, U19.6 (-)
unnamed: R39.2, R41.1, U19.13 (-)
unnamed: R40.2, R42.1, U19.7
unnamed: R41.2, R43.1, U19.14
OUT_L1: R20.1; also elsewhere on the board
OUT_L2: R21.1; also elsewhere on the board
OUT_L3: R22.1; also elsewhere on the board
OUT_L4: R23.1; also elsewhere on the board
OUT_L5: R24.1; also elsewhere on the board
OUT_L6: R25.1; also elsewhere on the board
OUT_L7: R26.1; also elsewhere on the board
OUT_L8: R27.1; also elsewhere on the board
OUT_R1: R28.1; also elsewhere on the board
OUT_R2: R29.1; also elsewhere on the board
OUT_R3: R30.1; also elsewhere on the board
OUT_R4: R31.1; also elsewhere on the board
OUT_R5: R32.1; also elsewhere on the board
OUT_R6: R33.1; also elsewhere on the board
OUT_R7: R34.1; also elsewhere on the board
OUT_R8: R35.1; also elsewhere on the board

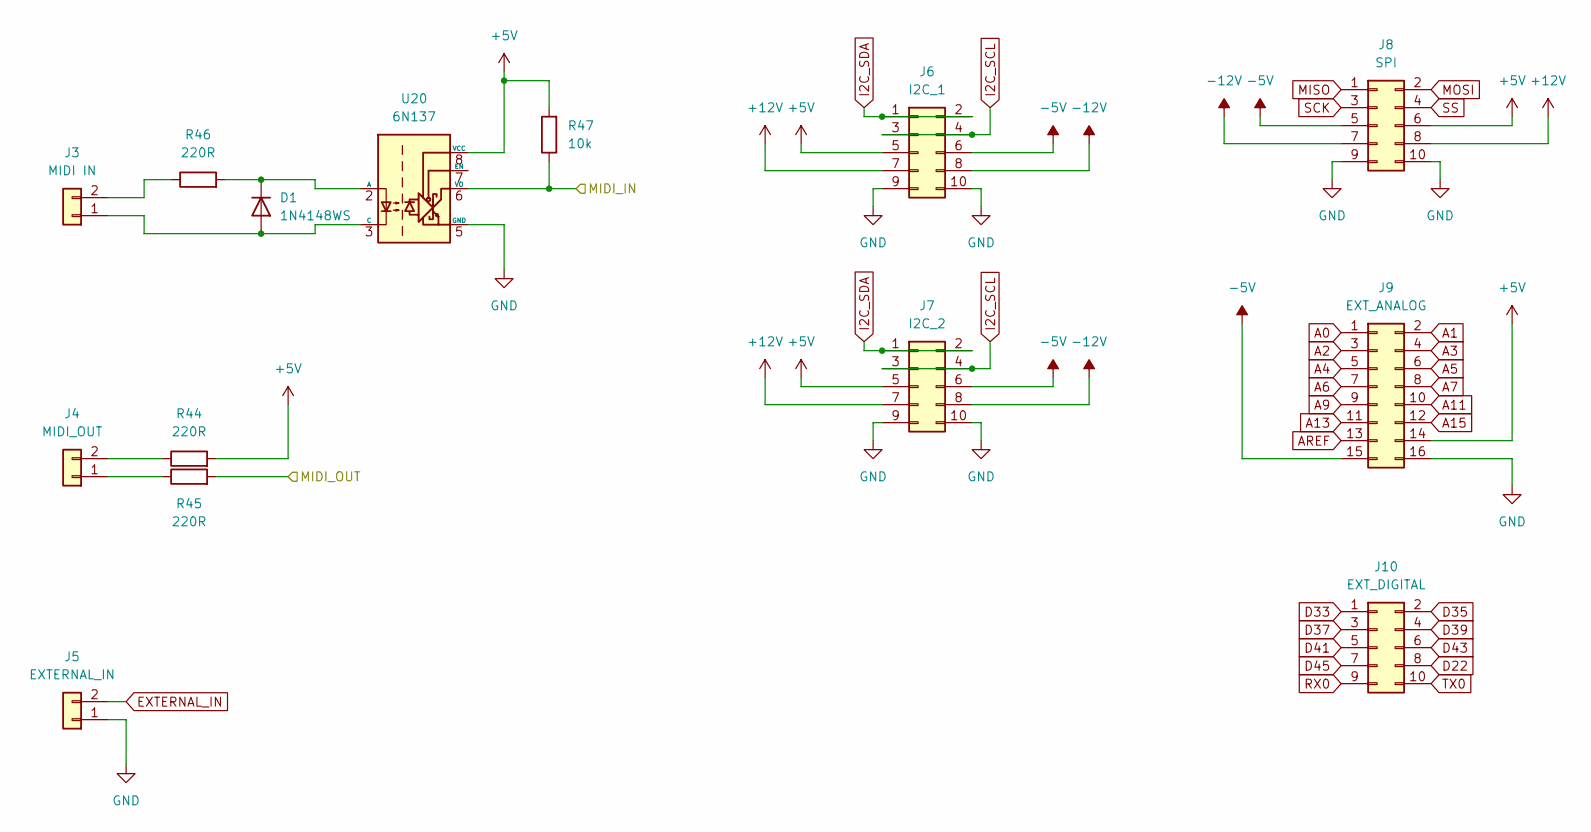
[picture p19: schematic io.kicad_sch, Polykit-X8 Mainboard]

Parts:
D1: 1N4148WS; D_SOD-323_HandSoldering
J3: MIDI IN; Molex_KK-254_AE-6410-02A_1x02_P2.54mm_Vertical
J4: MIDI_OUT; Molex_KK-254_AE-6410-02A_1x02_P2.54mm_Vertical
J5: EXTERNAL_IN; Molex_KK-254_AE-6410-02A_1x02_P2.54mm_Vertical
J6: I2C_1; IDC-Header_2x05_P2.54mm_Vertical
J7: I2C_2; IDC-Header_2x05_P2.54mm_Vertical
J8: SPI; IDC-Header_2x05_P2.54mm_Vertical
J9: EXT_ANALOG; IDC-Header_2x08_P2.54mm_Vertical
J10: EXT_DIGITAL; IDC-Header_2x05_P2.54mm_Vertical
R44, R45, R46: 220R; R_1206_3216Metric_Pad1.30x1.75mm_HandSolder
R47: 10k; R_1206_3216Metric_Pad1.30x1.75mm_HandSolder
U20: 6N137; DIP-8_W7.62mm_SMDSocket_SmallPads

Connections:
+5V: J6.5, J7.5, J8.6, J9.14, R44.2, R47.2, U20.8 (VCC); also elsewhere on the board
+12V: J6.7, J7.7, J8.8; also elsewhere on the board
-5V: J6.6, J7.6, J8.5, J9.15; also elsewhere on the board
-12V: J6.8, J7.8, J8.7; also elsewhere on the board
A0: J9.1; also elsewhere on the board
A1: J9.2; also elsewhere on the board
A2: J9.3; also elsewhere on the board
A3: J9.4; also elsewhere on the board
A4: J9.5; also elsewhere on the board
A5: J9.6; also elsewhere on the board
A6: J9.7; also elsewhere on the board
A7: J9.8; also elsewhere on the board
A9: J9.9; also elsewhere on the board
A11: J9.10; also elsewhere on the board
A13: J9.11; also elsewhere on the board
A15: J9.12; also elsewhere on the board
AREF: J9.13; also elsewhere on the board
D22: J10.8; also elsewhere on the board
D33: J10.1; also elsewhere on the board
D35: J10.2; also elsewhere on the board
D37: J10.3; also elsewhere on the board
D39: J10.4; also elsewhere on the board
D41: J10.5; also elsewhere on the board
D43: J10.6; also elsewhere on the board
D45: J10.7; also elsewhere on the board
EXTERNAL_IN: J5.2; also elsewhere on the board
GND: J5.1, J6.9, J6.10, J7.9, J7.10, J8.9, J8.10, J9.16, U20.5 (GND); also elsewhere on the board
I2C_SCL: J6.3, J6.4, J7.3, J7.4; also elsewhere on the board
I2C_SDA: J6.1, J6.2, J7.1, J7.2; also elsewhere on the board
MISO: J8.1; also elsewhere on the board
MOSI: J8.2; also elsewhere on the board
unnamed: D1.1 (K), R46.2, U20.2 (A)
unnamed: D1.2 (A), J3.1, U20.3 (C)
unnamed: J3.2, R46.1
unnamed: J4.1, R45.1
unnamed: J4.2, R44.1
RX0: J10.9; also elsewhere on the board
RX1: R47.1, U20.6 (VO); also elsewhere on the board
SCK: J8.3; also elsewhere on the board
SS: J8.4; also elsewhere on the board
TX0: J10.10; also elsewhere on the board
TX1: R45.2; also elsewhere on the board

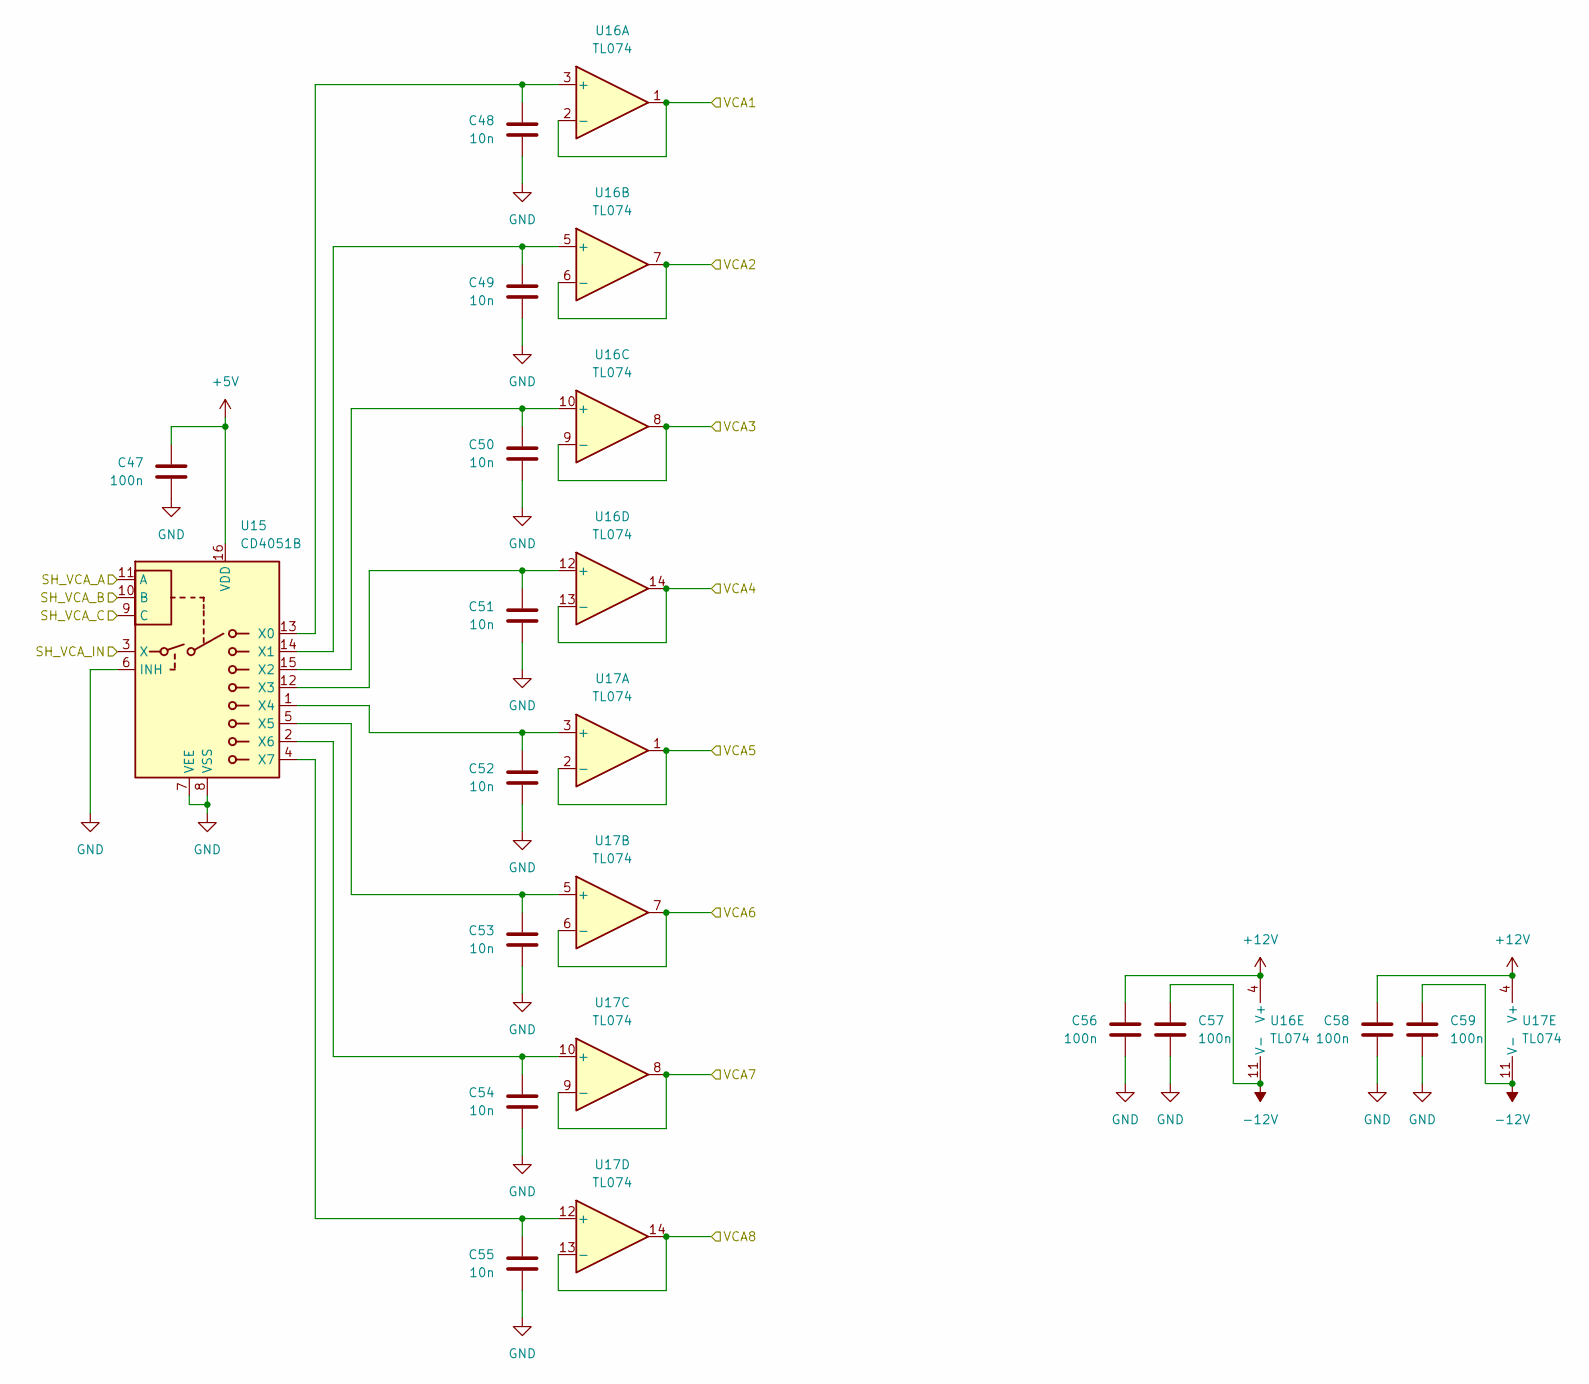
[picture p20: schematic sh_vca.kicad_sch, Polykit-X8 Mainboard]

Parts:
C47, C56, C57, C58, C59: 100n; C_1206_3216Metric_Pad1.33x1.80mm_HandSolder
C48, C49, C50, C51, C52, C53, C54, C55: 10n; C_1206_3216Metric_Pad1.33x1.80mm_HandSolder
U15: CD4051B; SO-16_5.3x10.2mm_P1.27mm
U16, U17: TL074; SO-14_3.9x8.65mm_P1.27mm

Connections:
+5V: C47.1, U15.16 (VDD); also elsewhere on the board
+12V: C56.1, C58.1, U16.4 (V+), U17.4 (V+); also elsewhere on the board
-12V: C57.1, C59.1, U16.11 (V-), U17.11 (V-); also elsewhere on the board
/DAC/DAC3: U15.3 (X); also elsewhere on the board
GND: C47.2, C48.2, C49.2, C50.2, C51.2, C52.2, C53.2, C54.2, C55.2, C56.2, C57.2, C58.2, C59.2, U15.6 (INH), U15.7 (VEE), U15.8 (VSS); also elsewhere on the board
unnamed: C48.1, U15.13 (X0), U16.3 (+)
unnamed: C49.1, U15.14 (X1), U16.5 (+)
unnamed: C50.1, U15.15 (X2), U16.10 (+)
unnamed: C51.1, U15.12 (X3), U16.12 (+)
unnamed: C52.1, U15.1 (X4), U17.3 (+)
unnamed: C53.1, U15.5 (X5), U17.5 (+)
unnamed: C54.1, U15.2 (X6), U17.10 (+)
unnamed: C55.1, U15.4 (X7), U17.12 (+)
SH_VCA_A: U15.11 (A); also elsewhere on the board
SH_VCA_B: U15.10 (B); also elsewhere on the board
SH_VCA_C: U15.9 (C); also elsewhere on the board
VCA1: U16.1, U16.2 (-); also elsewhere on the board
VCA2: U16.6 (-), U16.7; also elsewhere on the board
VCA3: U16.8, U16.9 (-); also elsewhere on the board
VCA4: U16.13 (-), U16.14; also elsewhere on the board
VCA5: U17.1, U17.2 (-); also elsewhere on the board
VCA6: U17.6 (-), U17.7; also elsewhere on the board
VCA7: U17.8, U17.9 (-); also elsewhere on the board
VCA8: U17.13 (-), U17.14; also elsewhere on the board

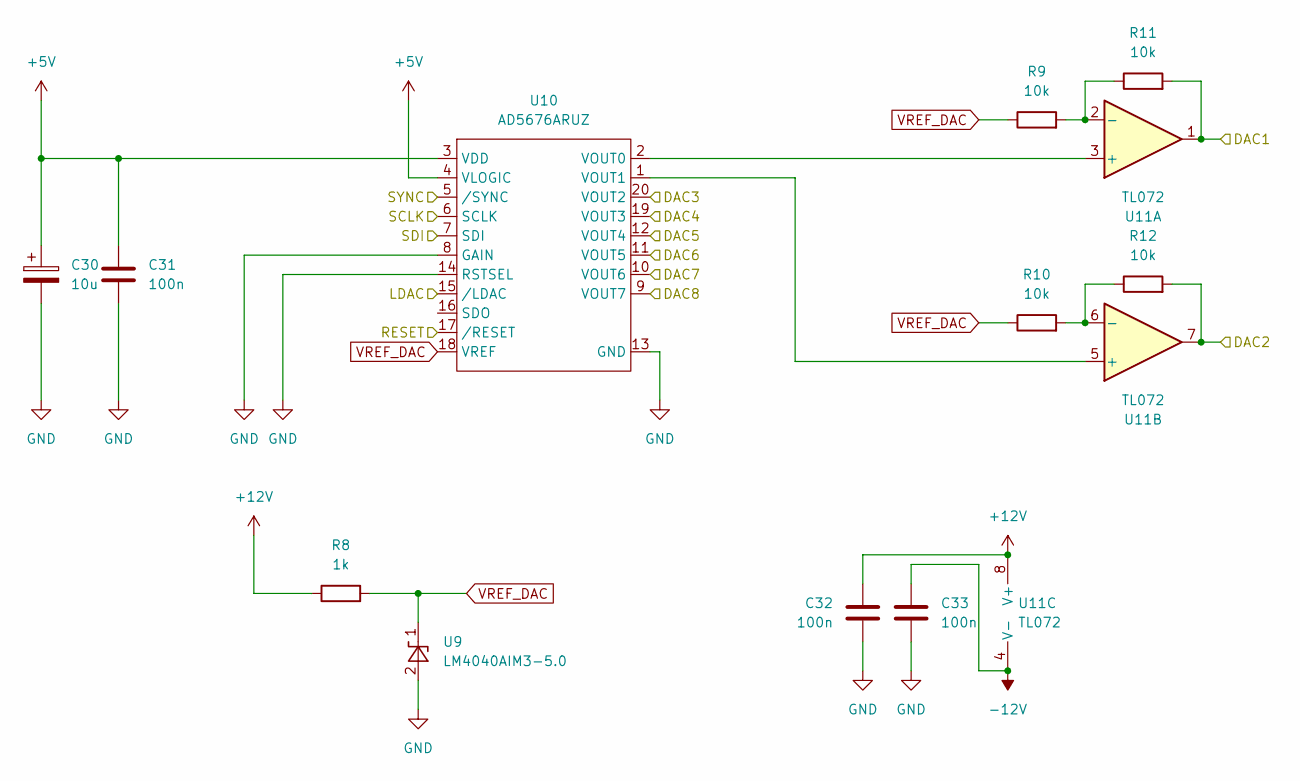
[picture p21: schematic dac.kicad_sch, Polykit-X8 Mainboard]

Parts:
C30: 10u; CP_Elec_5x5.9
C31, C32, C33: 100n; C_1206_3216Metric_Pad1.33x1.80mm_HandSolder
R8: 1k; R_1206_3216Metric_Pad1.30x1.75mm_HandSolder
R9, R10, R11, R12: 10k; R_1206_3216Metric_Pad1.30x1.75mm_HandSolder
U9: LM4040AIM3-5.0; SOT-23
U10: AD5676ARUZ; TSSOP-20_4.4x6.5mm_P0.65mm
U11: TL072; SO-8_3.9x4.9mm_P1.27mm

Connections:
+5V: C30.1, C31.1, U10.3 (VDD), U10.4 (VLOGIC); also elsewhere on the board
+12V: C32.1, R8.1, U11.8 (V+); also elsewhere on the board
-12V: C33.1, U11.4 (V-); also elsewhere on the board
/DAC/DAC1: R11.2, U11.1; also elsewhere on the board
/DAC/DAC3: U10.20 (VOUT2); also elsewhere on the board
/DAC/DAC4: U10.19 (VOUT3); also elsewhere on the board
/DAC/DAC7: U10.10 (VOUT6); also elsewhere on the board
/DAC/LDAC: U10.15 (/LDAC); also elsewhere on the board
/DAC/RESET: U10.17 (/RESET); also elsewhere on the board
DAC_FREQ: U10.11 (VOUT5); also elsewhere on the board
DAC_PAN: R12.2, U11.7; also elsewhere on the board
DAC_RES: U10.12 (VOUT4); also elsewhere on the board
DAC_SSYNC: U10.9 (VOUT7); also elsewhere on the board
GND: C30.2, C31.2, C32.2, C33.2, U9.2 (A), U10.8 (GAIN), U10.13 (GND), U10.14 (RSTSEL); also elsewhere on the board
MOSI: U10.7 (SDI); also elsewhere on the board
unnamed: R10.2, R12.1, U11.6 (-)
unnamed: R9.2, R11.1, U11.2 (-)
unnamed: U10.1 (VOUT1), U11.5 (+)
unnamed: U10.2 (VOUT0), U11.3 (+)
SCK: U10.6 (SCLK); also elsewhere on the board
SS: U10.5 (/SYNC); also elsewhere on the board
VREF_DAC: R8.2, R9.1, R10.1, U9.1 (K), U10.18 (VREF)

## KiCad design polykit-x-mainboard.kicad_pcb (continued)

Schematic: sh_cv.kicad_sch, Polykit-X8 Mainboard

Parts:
C15, C16, C17, C18, C23, C24, C25: 100n; C_1206_3216Metric_Pad1.33x1.80mm_HandSolder
C19, C20, C21, C22, C26, C27, C28, C29: 10n; C_1206_3216Metric_Pad1.33x1.80mm_HandSolder
R2, R3, R4, R5, R6, R7: 100k; R_1206_3216Metric_Pad1.30x1.75mm_HandSolder
U5: CD4051B; SO-16_5.3x10.2mm_P1.27mm
U6, U7, U8: TL074; SO-14_3.9x8.65mm_P1.27mm

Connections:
+5V: C15.1, U5.16 (VDD); also elsewhere on the board
+12V: C16.1, C18.1, C24.1, U6.4 (V+), U7.4 (V+), U8.4 (V+); also elsewhere on the board
-12V: C17.1, C23.1, C25.1, U6.11 (V-), U7.11 (V-), U8.11 (V-); also elsewhere on the board
/DAC/DAC7: U5.3 (X); also elsewhere on the board
DAC_ADSR_A: R5.2, U8.14; also elsewhere on the board
DAC_ADSR_D: R6.2, U8.8; also elsewhere on the board
DAC_ADSR_R: R7.2, U7.7; also elsewhere on the board
DAC_ADSR_S: U6.8, U6.9 (-); also elsewhere on the board
DAC_HSYNC: U8.6 (-), U8.7; also elsewhere on the board
DAC_LEVEL1: U7.8, U7.9 (-); also elsewhere on the board
DAC_LEVEL2: U7.13 (-), U7.14; also elsewhere on the board
DAC_PWM: U8.1, U8.2 (-); also elsewhere on the board
GND: C15.2, C16.2, C17.2, C18.2, C19.2, C20.2, C21.2, C22.2, C23.2, C24.2, C25.2, C26.2, C27.2, C28.2, C29.2, U5.6 (INH), U5.7 (VEE), U5.8 (VSS), U7.3 (+), U7.5 (+), U8.10 (+), U8.12 (+); also elsewhere on the board
unnamed: C19.1, U5.14 (X1), U6.3 (+)
unnamed: C20.1, U5.13 (X0), U6.5 (+)
unnamed: C21.1, U5.12 (X3), U6.10 (+)
unnamed: C22.1, U5.15 (X2), U6.12 (+)
unnamed: C26.1, U5.5 (X5), U7.10 (+)
unnamed: C27.1, U5.1 (X4), U7.12 (+)
unnamed: C28.1, U5.2 (X6), U8.3 (+)
unnamed: C29.1, U5.4 (X7), U8.5 (+)
unnamed: R2.1, U6.1, U6.2 (-)
unnamed: R2.2, R5.1, U8.13 (-)
unnamed: R3.1, U6.6 (-), U6.7
unnamed: R3.2, R6.1, U8.9 (-)
unnamed: R4.1, U6.13 (-), U6.14
unnamed: R4.2, R7.1, U7.6 (-)
unnamed: U7.1, U7.2 (-)
SH_CV_A: U5.11 (A); also elsewhere on the board
SH_CV_B: U5.10 (B); also elsewhere on the board
SH_CV_C: U5.9 (C); also elsewhere on the board

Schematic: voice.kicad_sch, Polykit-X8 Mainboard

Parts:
R1: 100k; R_1206_3216Metric_Pad1.30x1.75mm_HandSolder
VOICE1: VOICE; PinSocket_1x36_P2.54mm_Vertical

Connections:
+5V: VOICE1.4; also elsewhere on the board
+12V: VOICE1.2; also elsewhere on the board
-5V: VOICE1.5; also elsewhere on the board
-12V: VOICE1.3; also elsewhere on the board
/VOICES/VOICE1/ADSR_OUT: VOICE1.17
DAC_ADSR_A: VOICE1.11; also elsewhere on the board
DAC_ADSR_D: VOICE1.12; also elsewhere on the board
DAC_ADSR_R: VOICE1.14; also elsewhere on the board
DAC_ADSR_S: VOICE1.13; also elsewhere on the board
DAC_FREQ: VOICE1.30; also elsewhere on the board
DAC_HSYNC: VOICE1.10; also elsewhere on the board
DAC_LEVEL1: VOICE1.25; also elsewhere on the board
DAC_LEVEL2: VOICE1.26; also elsewhere on the board
DAC_PAN: VOICE1.28; also elsewhere on the board
DAC_PWM: VOICE1.7; also elsewhere on the board
DAC_RES: VOICE1.31; also elsewhere on the board
DAC_SSYNC: VOICE1.9; also elsewhere on the board
EXTERNAL_IN: VOICE1.29; also elsewhere on the board
FM1: VOICE1.8; also elsewhere on the board
GATE1: VOICE1.16; also elsewhere on the board
GND: VOICE1.1; also elsewhere on the board
unnamed: R1.1, VOICE1.6
OUT_L1: VOICE1.35; also elsewhere on the board
OUT_R1: VOICE1.36; also elsewhere on the board
PITCH1: R1.2; also elsewhere on the board
SW_EXTERNAL_ON: VOICE1.20; also elsewhere on the board
SW_FILTER_MODE_A: VOICE1.32; also elsewhere on the board
SW_FILTER_MODE_B: VOICE1.33; also elsewhere on the board
SW_FILTER_MODE_C: VOICE1.34; also elsewhere on the board
SW_FREQ_ADSR: VOICE1.22; also elsewhere on the board
SW_FREQ_ADSR_NEG: VOICE1.21; also elsewhere on the board
SW_RES_ADSR: VOICE1.23; also elsewhere on the board
SW_RES_ADSR_NEG: VOICE1.24; also elsewhere on the board
SW_SAW_ON: VOICE1.18; also elsewhere on the board
SW_TRIANGLE_ON: VOICE1.19; also elsewhere on the board
TRIG1: VOICE1.15; also elsewhere on the board
VCA1: VOICE1.27; also elsewhere on the board

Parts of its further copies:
R13, R14, R15, R16, R17, R18, R19: 100k; R_1206_3216Metric_Pad1.30x1.75mm_HandSolder
VOICE2, VOICE3, VOICE4, VOICE5, VOICE6, VOICE7, VOICE8: VOICE; PinSocket_1x36_P2.54mm_Vertical

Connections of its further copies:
+5V: VOICE2.4, VOICE3.4, VOICE4.4, VOICE5.4, VOICE6.4, VOICE7.4, VOICE8.4; also elsewhere on the board
+12V: VOICE2.2, VOICE3.2, VOICE4.2, VOICE5.2, VOICE6.2, VOICE7.2, VOICE8.2; also elsewhere on the board
-5V: VOICE2.5, VOICE3.5, VOICE4.5, VOICE5.5, VOICE6.5, VOICE7.5, VOICE8.5; also elsewhere on the board
-12V: VOICE2.3, VOICE3.3, VOICE4.3, VOICE5.3, VOICE6.3, VOICE7.3, VOICE8.3; also elsewhere on the board
/VOICES/VOICE2/ADSR_OUT: VOICE2.17
/VOICES/VOICE3/ADSR_OUT: VOICE3.17
/VOICES/VOICE4/ADSR_OUT: VOICE4.17
/VOICES/VOICE5/ADSR_OUT: VOICE5.17
/VOICES/VOICE6/ADSR_OUT: VOICE6.17
/VOICES/VOICE7/ADSR_OUT: VOICE7.17
/VOICES/VOICE8/ADSR_OUT: VOICE8.17
DAC_ADSR_A: VOICE2.11, VOICE3.11, VOICE4.11, VOICE5.11, VOICE6.11, VOICE7.11, VOICE8.11; also elsewhere on the board
DAC_ADSR_D: VOICE2.12, VOICE3.12, VOICE4.12, VOICE5.12, VOICE6.12, VOICE7.12, VOICE8.12; also elsewhere on the board
DAC_ADSR_R: VOICE2.14, VOICE3.14, VOICE4.14, VOICE5.14, VOICE6.14, VOICE7.14, VOICE8.14; also elsewhere on the board
DAC_ADSR_S: VOICE2.13, VOICE3.13, VOICE4.13, VOICE5.13, VOICE6.13, VOICE7.13, VOICE8.13; also elsewhere on the board
DAC_FREQ: VOICE2.30, VOICE3.30, VOICE4.30, VOICE5.30, VOICE6.30, VOICE7.30, VOICE8.30; also elsewhere on the board
DAC_HSYNC: VOICE2.10, VOICE3.10, VOICE4.10, VOICE5.10, VOICE6.10, VOICE7.10, VOICE8.10; also elsewhere on the board
DAC_LEVEL1: VOICE2.25, VOICE3.25, VOICE4.25, VOICE5.25, VOICE6.25, VOICE7.25, VOICE8.25; also elsewhere on the board
DAC_LEVEL2: VOICE2.26, VOICE3.26, VOICE4.26, VOICE5.26, VOICE6.26, VOICE7.26, VOICE8.26; also elsewhere on the board
DAC_PAN: VOICE2.28, VOICE3.28, VOICE4.28, VOICE5.28, VOICE6.28, VOICE7.28, VOICE8.28; also elsewhere on the board
DAC_PWM: VOICE2.7, VOICE3.7, VOICE4.7, VOICE5.7, VOICE6.7, VOICE7.7, VOICE8.7; also elsewhere on the board
DAC_RES: VOICE2.31, VOICE3.31, VOICE4.31, VOICE5.31, VOICE6.31, VOICE7.31, VOICE8.31; also elsewhere on the board
DAC_SSYNC: VOICE2.9, VOICE3.9, VOICE4.9, VOICE5.9, VOICE6.9, VOICE7.9, VOICE8.9; also elsewhere on the board
EXTERNAL_IN: VOICE2.29, VOICE3.29, VOICE4.29, VOICE5.29, VOICE6.29, VOICE7.29, VOICE8.29; also elsewhere on the board
FM2: VOICE2.8; also elsewhere on the board
FM3: VOICE3.8; also elsewhere on the board
FM4: VOICE4.8; also elsewhere on the board
FM5: VOICE5.8; also elsewhere on the board
FM6: VOICE6.8; also elsewhere on the board
FM7: VOICE7.8; also elsewhere on the board
FM8: VOICE8.8; also elsewhere on the board
GATE2: VOICE2.16; also elsewhere on the board
GATE3: VOICE3.16; also elsewhere on the board
GATE4: VOICE4.16; also elsewhere on the board
GATE5: VOICE5.16; also elsewhere on the board
GATE6: VOICE6.16; also elsewhere on the board
GATE7: VOICE7.16; also elsewhere on the board
GATE8: VOICE8.16; also elsewhere on the board
GND: VOICE2.1, VOICE3.1, VOICE4.1, VOICE5.1, VOICE6.1, VOICE7.1, VOICE8.1; also elsewhere on the board
unnamed: R13.1, VOICE2.6
unnamed: R14.1, VOICE3.6
unnamed: R15.1, VOICE4.6
unnamed: R16.1, VOICE5.6
unnamed: R17.1, VOICE6.6
unnamed: R18.1, VOICE7.6
unnamed: R19.1, VOICE8.6
OUT_L2: VOICE2.35; also elsewhere on the board
OUT_L3: VOICE3.35; also elsewhere on the board
OUT_L4: VOICE4.35; also elsewhere on the board
OUT_L5: VOICE5.35; also elsewhere on the board
OUT_L6: VOICE6.35; also elsewhere on the board
OUT_L7: VOICE7.35; also elsewhere on the board
OUT_L8: VOICE8.35; also elsewhere on the board
OUT_R2: VOICE2.36; also elsewhere on the board
OUT_R3: VOICE3.36; also elsewhere on the board
OUT_R4: VOICE4.36; also elsewhere on the board
OUT_R5: VOICE5.36; also elsewhere on the board
OUT_R6: VOICE6.36; also elsewhere on the board
OUT_R7: VOICE7.36; also elsewhere on the board
OUT_R8: VOICE8.36; also elsewhere on the board
PITCH2: R13.2; also elsewhere on the board
PITCH3: R14.2; also elsewhere on the board
PITCH4: R15.2; also elsewhere on the board
PITCH5: R16.2; also elsewhere on the board
PITCH6: R17.2; also elsewhere on the board
PITCH7: R18.2; also elsewhere on the board
PITCH8: R19.2; also elsewhere on the board
SW_EXTERNAL_ON: VOICE2.20, VOICE3.20, VOICE4.20, VOICE5.20, VOICE6.20, VOICE7.20, VOICE8.20; also elsewhere on the board
SW_FILTER_MODE_A: VOICE2.32, VOICE3.32, VOICE4.32, VOICE5.32, VOICE6.32, VOICE7.32, VOICE8.32; also elsewhere on the board
SW_FILTER_MODE_B: VOICE2.33, VOICE3.33, VOICE4.33, VOICE5.33, VOICE6.33, VOICE7.33, VOICE8.33; also elsewhere on the board
SW_FILTER_MODE_C: VOICE2.34, VOICE3.34, VOICE4.34, VOICE5.34, VOICE6.34, VOICE7.34, VOICE8.34; also elsewhere on the board
SW_FREQ_ADSR: VOICE2.22, VOICE3.22, VOICE4.22, VOICE5.22, VOICE6.22, VOICE7.22, VOICE8.22; also elsewhere on the board
SW_FREQ_ADSR_NEG: VOICE2.21, VOICE3.21, VOICE4.21, VOICE5.21, VOICE6.21, VOICE7.21, VOICE8.21; also elsewhere on the board
SW_RES_ADSR: VOICE2.23, VOICE3.23, VOICE4.23, VOICE5.23, VOICE6.23, VOICE7.23, VOICE8.23; also elsewhere on the board
SW_RES_ADSR_NEG: VOICE2.24, VOICE3.24, VOICE4.24, VOICE5.24, VOICE6.24, VOICE7.24, VOICE8.24; also elsewhere on the board
SW_SAW_ON: VOICE2.18, VOICE3.18, VOICE4.18, VOICE5.18, VOICE6.18, VOICE7.18, VOICE8.18; also elsewhere on the board
SW_TRIANGLE_ON: VOICE2.19, VOICE3.19, VOICE4.19, VOICE5.19, VOICE6.19, VOICE7.19, VOICE8.19; also elsewhere on the board
TRIG2: VOICE2.15; also elsewhere on the board
TRIG3: VOICE3.15; also elsewhere on the board
TRIG4: VOICE4.15; also elsewhere on the board
TRIG5: VOICE5.15; also elsewhere on the board
TRIG6: VOICE6.15; also elsewhere on the board
TRIG7: VOICE7.15; also elsewhere on the board
TRIG8: VOICE8.15; also elsewhere on the board
VCA2: VOICE2.27; also elsewhere on the board
VCA3: VOICE3.27; also elsewhere on the board
VCA4: VOICE4.27; also elsewhere on the board
VCA5: VOICE5.27; also elsewhere on the board
VCA6: VOICE6.27; also elsewhere on the board
VCA7: VOICE7.27; also elsewhere on the board
VCA8: VOICE8.27; also elsewhere on the board

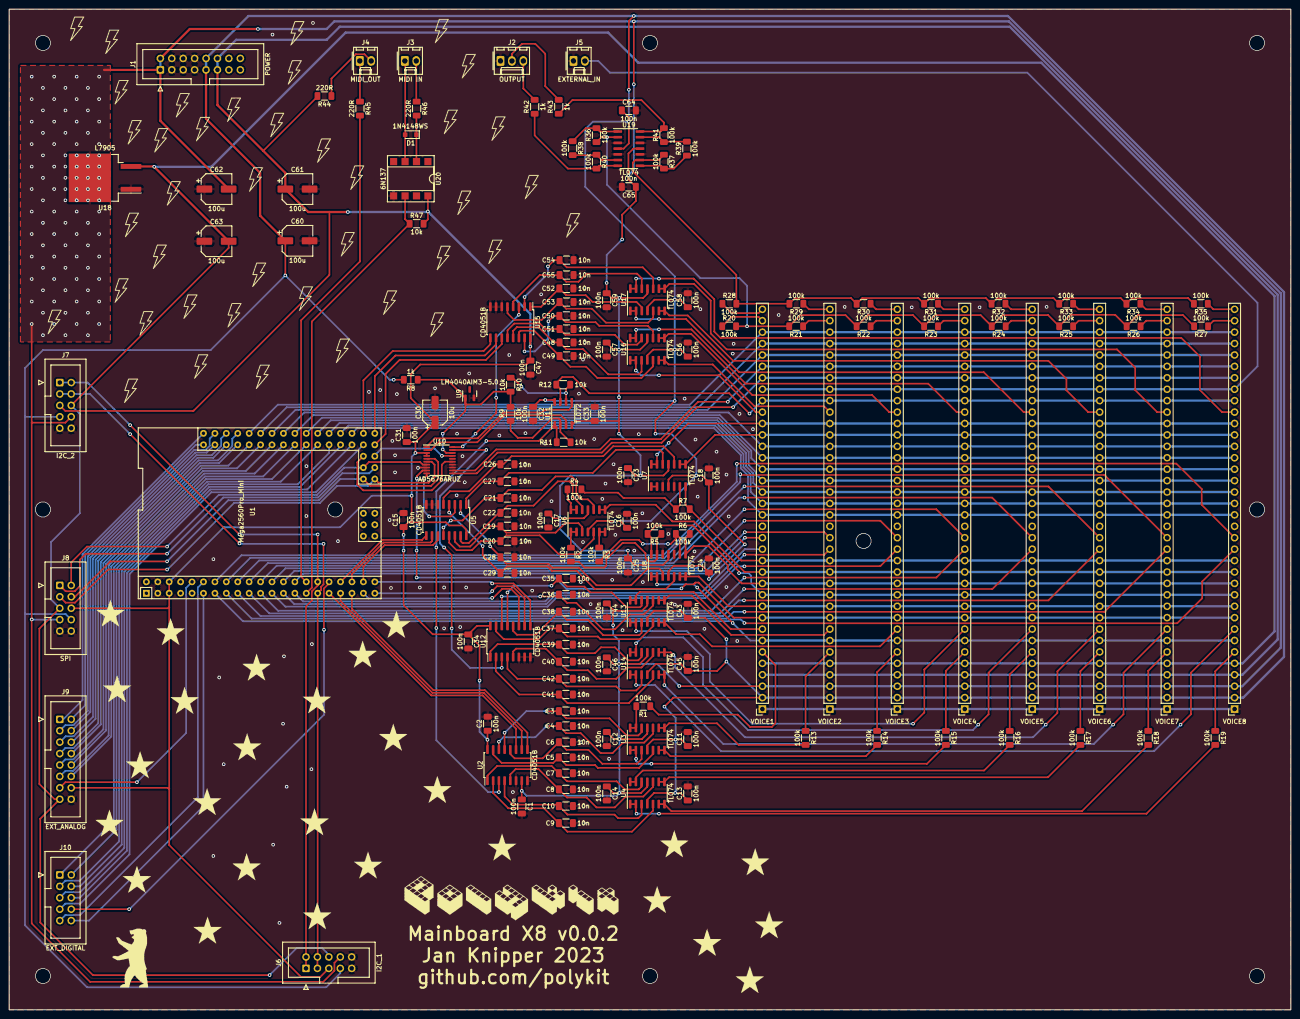
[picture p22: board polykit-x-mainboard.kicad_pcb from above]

Board: 2 copper layers, 285.0 x 222.5 mm, 151 parts (0 on the bottom side), 200 nets.

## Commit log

2024-01-14 Initial import
    [dac.kicad_sch, io.kicad_sch, mixer.kicad_sch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]
2024-01-14 Add board rendering
2024-01-14 Add BOM
